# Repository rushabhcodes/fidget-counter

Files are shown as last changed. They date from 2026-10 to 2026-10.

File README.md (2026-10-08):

# MagSafe BLE Fidget Counter — PCB Rev A

> **Current revision 1.0.6: top battery access, a cap with two deliberate release latches, solid bottom cover with 24 magnet pockets, imported CR2032 holder, 0.30 mm via drill / 0.55 mm via land, green mask, double-sided Standard PCBA and ENIG.** TMAG3001A2YBGR is retained. This is a checked prototype ready for supplier quotation/CAM review; the assembly order has not been released.

The default registry entrypoint is `published.circuit.json`, the exact validated routed board and enclosure assembly. `bun run build` renders that saved board; `bun run build:source` rebuilds the editable TSX using the prescribed routing. `bun run check:all` rebuilds and validates the editable TSX, including routing and exported copper. The published circuit is refreshed from that checked build.

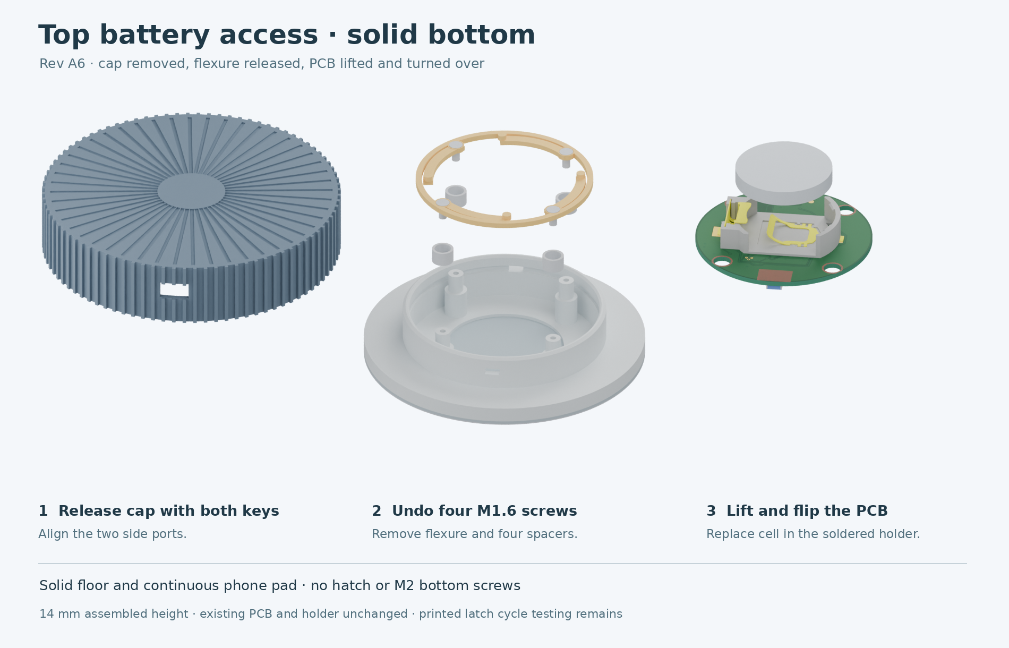
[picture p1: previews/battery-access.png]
Top battery access and revised enclosure


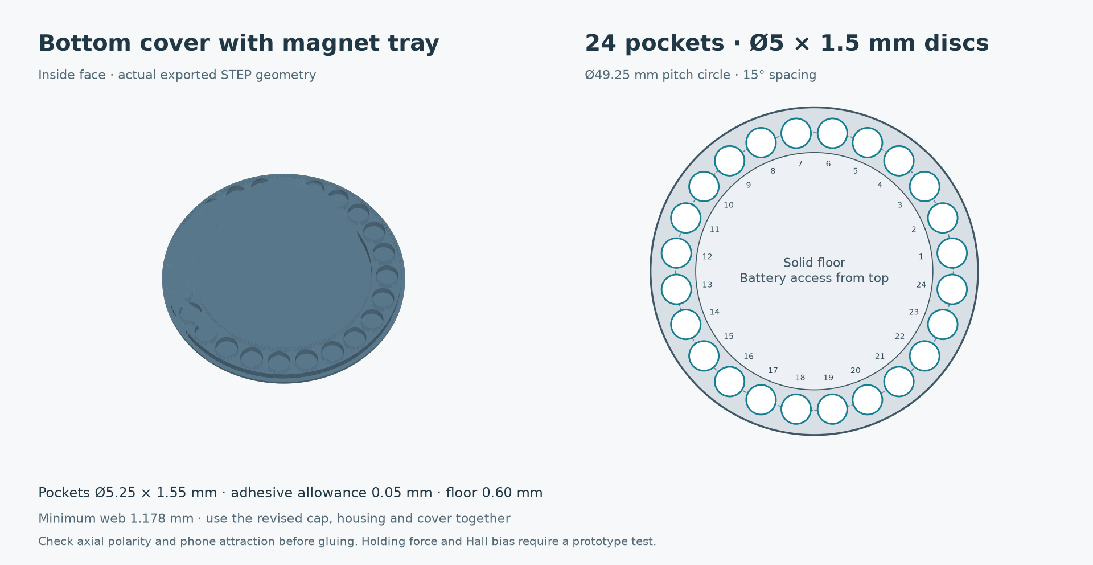
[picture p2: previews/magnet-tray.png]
Bottom cover magnet pockets


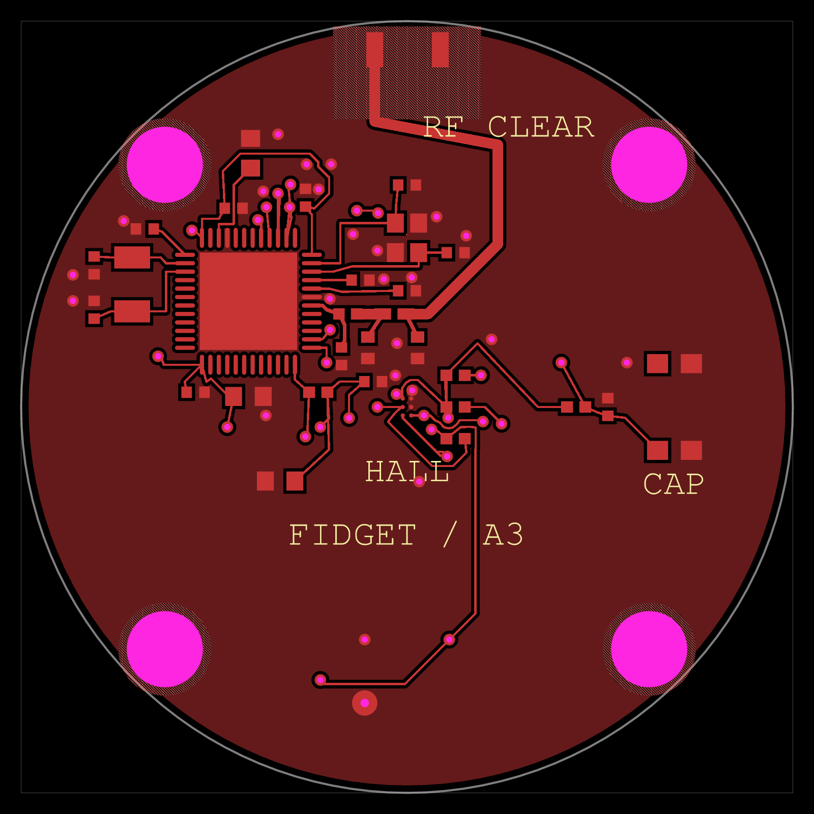
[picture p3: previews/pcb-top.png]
Validated routed PCB


A 36.5 mm circular, two-layer, 1.0 mm PCB for the revised 14.0 mm rotating-cap enclosure. The nRF52810-QFAA reference, its power circuitry, crystals and initial RF matching values come from [seveibar/nrf52810](https://tscircuit.com/seveibar/nrf52810#files), installed as `@tsci/seveibar.nrf52810@0.1.3`. This is a new circular layout; the reference's RF qualification does not carry over.

The central TMAG3001A2 measures the diametric encoder magnet's XY angle. A cap-operated tactile switch supports a two-second count-reset hold in firmware. BT1 is the bottom-mounted MYOUNG BS-08-B2AA020-R holder (JLCPCB C964787), imported with its exact footprint and 3D model. The CR2032 is replaced from above: release the two cap latches, remove the four flexure/PCB screws, then lift and flip the board with its soldered holder. The cell positive face points toward the solid bottom cover. Five underside pogo pads provide SWD access. No LED, charging circuit or tall programming connector is fitted.

## Open and build

```sh
bun install --frozen-lockfile
bun run dev
bun run check:all
```

Use the project's local CLI through `bun run tsci` to keep the tool version consistent with the lockfile. At project initialization, tscircuit 0.0.2748 and CLI 0.1.2253 were verified against the official npm registry. See `bun.lock` for installed dependency versions.

`check:all` runs TypeScript, every TSCI check command, a source build, the full `@tscircuit/checks` validator, and Gerber-derived shorts on both layers. It analyzes trace lengths for every electrical net and requires all eight crystal signal branches to be at most 10 mm with zero vias. Results and source hashes go to `work/`. It fails on design errors, warnings, actionable placement issues or an asynchronous tool exception. Routing difficulty is an advisory congestion estimate; successful routing and DRC determine the final result.

The board uses an explicit parts engine that returns the authored supplier identifiers. Pin roles and manufacturer choices come from the listed datasheets and BOM, so checks do not replace them with remote supplier suggestions. No design-rule check is disabled.

`index.circuit.tsx` defines placement, nets, four schematic sheets and local routing. `routing.ts` uses tscircuit's local custom-router API to load the remaining edited copper branches from `routed-paths.json`. Its terminal signature rejects stale routes after placement/connectivity changes. The supplied routing is prescribed and reproducible; all normal DRC, pour, connection and shorts checks remain enabled. `imports/` contains unmodified TSCI JLCPCB imports with downloaded OBJ/STEP models. `parts.tsx` and `passives.tsx` add electrical pin roles and select those library parts. Imported copper, pad numbers, courtyards and model files are preserved; supplier silkscreen graphics are omitted where the board uses its own legend. Bare diagnostic and programming lands use standard footprint generators. The physical MCU is declared once and split into sheet-local schematic boxes.

## JLCPCB library imports

The parts were located with `tsci search --jlcpcb --json`, matched by exact manufacturer part number, then imported with `tsci import --jlcpcb --download --use-exact-footprint C<number>`. The exact-footprint flag keeps supplier geometry instead of substituting a similar footprint generator. `validation/jlc-imports.json` records the commands, catalog identifiers and SHA-256 hashes of all generated TSX/OBJ/STEP files. Stock returned by search is cached; it is not an assembly reservation.

**SW1 exception:** the existing 2 N KMR223NG ULC LFG / Y78B22324FP has no verified JLCPCB catalog identifier. Its footprint and visual model reuse the imported KMR232NGULCLFS (C221681) geometry: both share the manufacturer's KMR2 package/land drawing. The fitted part remains the original 2 N switch. C221681 is deliberately absent from SW1's supplier identifiers and assembly BOM because it is the 3 N variant. A substitution to that variant awaits the user's preference; exact 2 N procurement or consignment remains open. There are no hand-drawn component copper footprints in the project.

For local 3D output, use `bun run tsci build index.circuit.tsx --glbs --3d-png`. This CLI version's standalone JSON-to-GLB export resolves project-relative model URLs against the registry; its build path resolves downloaded files correctly. Model meshes have been checked in the built GLB. Imported visual models are assembly illustrations, not tolerance-certified mechanical drawings.

## Hardware and firmware handoff

| Signal | nRF52810 GPIO / physical QFAA pin | Peripheral |
|---|---|---|
| SCL | P0.26 / 38 | U2 C2, 10 kΩ pull-up |
| SDA | P0.27 / 39 | U2 C1, 10 kΩ pull-up |
| HALL_INT | P0.28 / 40 | U2 B1, active-low open drain, 10 kΩ pull-up |
| CAP_PRESS | P0.29 / 41 | SW1 closes to GND, 100 kΩ pull-up, 10 nF filter |
| SWDCLK | 25 | TP_SWDCLK |
| SWDIO | 26 | TP_SWDIO |
| nRESET | P0.21 / 24 | TP_RESET, 100 kΩ pull-up |
| LF crystal | P0.00 / 2, P0.01 / 3 | 32.768 kHz |
| HF crystal | XC1 / 34, XC2 / 35 | 32 MHz |

Supply is the CR2032 directly, nominal 3 V. U1 operates from 1.7–3.6 V and U2 from 1.65–3.6 V. Set **DCDCEN = 0**: this retains the reference's LDO-mode circuit, with no DC/DC inductors fitted. DEC pins supply only their associated decoupling capacitors. Configure P0.21 as nRESET if hardware reset is desired; CAP_PRESS clears the count in firmware and is a separate GPIO.

Start I2C at 100 kHz with the fitted 10 kΩ pull-ups. U2 ADDR is grounded: the seven-bit address is **0x34**. Per TI, ADDR is sampled only in standby/continuous mode. Before entering sleep or wake-and-sleep mode, explicitly program the device's I2C address and enable its software address override. Start with the ±240 mT range and XY measurements, check saturation, and calibrate field offsets and gain with the coin cell, phone and attachment magnets installed. Package center is at (0,0); the chip's internal Hall elements have the manufacturer's intrinsic offsets.

At rest, use the sensor's wake-and-sleep mode and a magnetic-change interrupt to wake U1. Clear the interrupt promptly; an asserted open-drain output draws current through R3. Increase the sample rate while moving. Integrate wrapped signed angle differences; count complete 360° increments without incrementing for small reversals across zero. Choose a sampling interval that bounds the maximum expected intersample rotation below 180°, or add velocity-based rejection. Debounce SW1 and clear the stored count after a continuous two-second press. Keep BLE advertising/notification intervals sparse and batch updates. Firmware and a phone app are not included in this PCB project.

## Assembly and tuning

See **MECHANICAL.md** for mounting coordinates, the required cap-pusher change and the imported holder and top battery access. See **BOM.csv** for assembly values and source identifiers. C13/C14 are DNP tuning sites; their initial values describe candidate capacitors, not fitted parts.

The reference's 3.9 nH / 0.8 pF chip matching and 6.8 nH antenna matching are starting values. The new feed and circular ground geometry need RF measurement and tuning in the final enclosure against the intended phone. A 0.5 mm feed width is the retained routing starting value, not a verified 50 Ω transmission line. Confirm the fabricator's actual stackup and recalculate the feed/ground geometry before an RF-qualified production release. Measure crystal startup/frequency and adjust the 12 pF load capacitors if needed.

U2 is a six-ball 0.4 mm-pitch WCSP. The exact JLCPCB/EasyEDA import uses 0.20 mm lands, while TI's recommended land drawing uses 0.23 mm. The imported footprint is retained as requested; the assembler must review this difference and stencil/reflow suitability before an order. The current sensor is cataloged as JLCPCB C31115089; it remains in this design by request. Stock and preorder availability are not guaranteed. The exact SW1 switch has no verified JLCPCB assembly listing; procurement or consignment needs confirmation. The fabrication export adds the core’s missing QFN lead paste apertures at its normal 70% linear size reduction and excludes paste from bare/DNP sites. The generated QFN exposed-pad paste is a single 3.22 × 3.22 mm aperture over the 4.6 × 4.6 mm copper land. Have the assembler review and segment that aperture for its stencil/reflow process before ordering assembly.

The BOM specifies imported Murata RF/passive parts, Yageo resistors and a Samsung 1 µF C10. C10 is CL10B105KA8NNWC (25 V, X7R, ±10%, 0603), replacing the previously unresolved Murata part. All fitted passive footprints and models come from their exact JLCPCB imports. Capacitor DC-bias derating and RF performance still need prototype measurements. `Assembly_Position_Reference.csv` contains authored coordinates and rotations, which the assembler must map to its own component conventions. BT1 is fitted on the underside; the other 29 fitted components are on top. Soldermask covers both ground pours, and vias are tented on both sides.

Both oscillators use native crystal models with electrical length/via constraints. X1 uses the imported manufacturer's pad numbers directly: 1 and 3 are crystal terminals, and 2 and 4 are grounded case pads. Its authored PCB rotation is 90°. X1 is a 32 MHz, 8 pF-load crystal; X2 is 32.768 kHz with a 9 pF load. The four 12 pF external capacitors are initial values that include an allowance for PCB and pin parasitics.

PCB checks verify connectivity and geometry. Physical rotation accuracy, BLE range, current consumption and battery/contact life require a populated prototype. `VALIDATION.md` records the actual final tool results.

## JLCPCB fabrication and assembly settings

Keep U2 TMAG3001A2YBGR. Target **Standard PCBA, both sides**, with **ENIG**, green soldermask, 2 layers, 1 oz copper and 1.0 mm finished thickness. Use regular routed outline tolerance (±0.2 mm), regular minimum via option (0.3 mm drill), and tented vias. The routed design uses **0.30 mm drill / 0.55 mm land**; GPIO escape lands use the same geometry and have no inserted component.

The imported sensor mask bridges are 0.20 mm, so green mask is specified. Printed text is 1.7 mm nominal height with a 0.153 mm stroke; pin-one markers use 0.15 mm strokes. Default passive outlines that overlapped nearby mask openings are omitted. `validation/jlc-geometry-audit.json` records measured copper/drill clearances, and `validation/jlc-gerber-audit.json` checks the exported mask and legend; these independent checks supplement the TSCI checks.

The 36.5 mm circle needs a carrier for Standard PCBA. Ask JLCPCB to panelize the single-board Gerbers into a panel at least 70 × 70 mm, with 5 mm handling rails, tooling holes and fiducials. Use mouse-bite tabs clear of the antenna and mounting holes. Confirm tab locations and finished-circle clearance with CAM; depanelization leaves local tab remnants. The supplied Gerber ZIP is a single-board definition, not a fabricated carrier panel.

The bottom-mounted holder adds a second assembly side; confirm reflow order, retention/fixture needs and any handling charge with JLCPCB. Normal Standard assembly setup, stencil, feeder loading, inspection, ENIG, panelization, component and shipping costs remain. The drill, copper and mask changes aim to avoid unnecessary fabrication options. A supplier quote and CAM review are still required to confirm all charges; no final price or zero-surcharge guarantee has been obtained.

`BOM.csv` distinguishes verified catalog identities, retained reference mappings and unresolved exact-MPN sourcing. `JLCPCB_BOM_Quote_Draft.csv` includes fitted parts only; `JLCPCB_CPL_Quote_Draft.csv` gives single-board positions in millimetres. Both contain 30 designators (29 top and BT1 bottom). Rotations are authored rotations and must be visually matched to JLCPCB's models, particularly U1, U2, X1, X2, ANT1 and SW1. Confirm the QFN exposed-pad stencil apertures with the assembler. ANT1's [catalog listing](https://jlcpcb.com/partdetail/Walsin_TechCorp-RFANT3216120A5T/C127629) carries a fixture notice; confirm whether a fixture is required and its charge. C10, C15 and L2 now have exact imported catalog identifiers. SW1 still requires exact-part sourcing confirmation; U2 and the four crystal load capacitors need stock confirmation for the selected quantity.

The mounting-hole web remains 0.25 mm nominal, inherited from the enclosure. Obtain explicit CAM acceptance, or revise the hole positions and enclosure together. This handoff is ready for supplier review and quotation, with the unresolved items stated; it is not released for an assembly order.

Current primary requirements: [rigid PCB capabilities](https://jlcpcb.com/capabilities/pcb-capabilities), [assembly capabilities](https://jlcpcb.com/capabilities/pcb-assembly-capabilities), [surcharge rules](https://jlcpcb.com/help/article/in-what-cases-will-there-be-charged-extra), [assembly charges](https://jlcpcb.com/help/article/pcb-assembly-price).

## Handoff files

- Root TSX files, package/configuration files and lockfile: editable tscircuit project.
- `verify.mjs`: repeatable full check runner, invoked with `bun run check:all`.
- `published.circuit.json`: exact checked routed circuit used for the registry and supplied exports. The default build writes it to `dist/published/circuit.json`.
- `previews/`: copper layout views, a fitted-part assembly reference and all four schematic sheets in PNG/SVG. `pcb-bottom` shows the actual underside orientation; `pcb-bottom-top-coordinates` retains the source coordinate view. The assembly reference excludes DNP parts, GPIO escape lands and bare test/contact interfaces; crystal manufacturer pin numbering is documented above. Library model downloads are included under `imports/`, with the full device GLB and PNG at `previews/3d.*` and the unchanged bare PCB view at `previews/pcb-3d.*`.
- `fabrication/`: prototype Gerber/drill ZIP and assembly position reference CSV.
- `BOM.csv` and `netlist.txt`: assembly intent and electrical connectivity.
- `mechanical/`: all four compatible printed enclosure parts in STL/STEP, editable CadQuery source/parameters and geometry validation.
- `validation/`: final check logs, warning inventory and source/circuit hashes.

Treat the Gerbers as a prototype review handoff. Resolve the thin mounting-hole web with the fabricator and the stencil/land-pattern details with the assembler before placing an order. RF tuning and magnetic calibration remain prototype measurements.

The fabrication ZIP contains Gerber and drill files only. Use the separate authored BOM and assembly position reference; automatically generated supplier BOM/rotation files have been omitted.

Run `bun run export:gerbers` after `bun run check:all` to produce the fabrication ZIP; this preserves supplier copper geometry and fills the missing QFN lead paste records. To repeat the independent JLC geometry/export audits, install `validation/requirements.txt` into a local Python virtual environment, then run `validation/check-jlc.py published.circuit.json` and `validation/check-jlc-gerbers.py fabrication/Fidget_Counter_RevA_Prototype_Gerbers.zip published.circuit.json` from the project root. These produce reports in `work/` and fail on the measured rule violations.

## Enclosure in the circuit's 3D view

`index.circuit.tsx` wraps the board in `<assembly.device>` and adds `EnclosureAssembly` from `enclosure.tsx`. Its 12 named `<assembly.cadassembly>` elements load the existing enclosure geometry alongside the actual populated PCB. There are no duplicate electronics or holder dummies. The three outer shells are translucent to expose the interior; STL/STEP solids retain their original geometry.

The models use millimetres and Z-up assembly coordinates. Their offset is Z = −7.6 mm because tscircuit places the PCB midplane at Z = 0. This preserves the released cap, holder and cell stack. The central encoder uses the user-specified diametrically magnetized neodymium Ø5 × 1.5 mm disc, a Ø5.2 mm pocket and a 0.2 mm roof shim. Its nominal released/pressed sensor gaps remain 1.8/1.3 mm; magnet grade and field calibration are unverified. `mechanical/Circuit_Models/manifest.json` records model bounds and hashes. The bottom cover now locates 24 separate Ø5 × 1.5 mm discs on a Ø49.25 mm pitch circle. Its inside-face pockets are Ø5.25 × 1.55 mm, including 0.05 mm adhesive allowance. The housing accepts the thicker cover tray and a Ø44.05 / Ø54.45 × 0.7 mm steel backing ring; overall enclosure height remains 14 mm. Use this revision's cap, housing and solid bottom cover together. The two release keys and PCB lift pick are included as printable tools. See `MECHANICAL.md` for loading order and polarity checks; holding force, ordered magnetization and phone compatibility are unverified.

The CadQuery builder also writes `Circuit_Models/` into its output directory. After revising the CAD, copy those generated assets into `mechanical/Circuit_Models/`, rebuild the source, then run `bun run check:enclosure` to verify model alignment and unchanged electrical geometry. The downloadable GLB is compacted for the registry upload limit. It preserves every position, triangle index, node transform, electronic model and board texture byte-for-byte; viewers derive flat normals for the untextured enclosure models. Repeat this export step after a source build:

```sh
python3 validation/compact-glb.py dist/index/3d.glb previews/3d.glb --report validation/compact-glb-audit.json
```

The assembly API follows the [TSCI cadassembly documentation](https://docs.tscircuit.com/elements/assembly-cadassembly).

## Primary design sources

- Reference board: https://tscircuit.com/seveibar/nrf52810#files
- Nordic reference circuitry: https://docs.nordicsemi.com/r/bundle/ps_nrf52810/page/ref_circuitry.html
- TI TMAG3001 datasheet, SLYS053C: https://www.ti.com/lit/ds/symlink/tmag3001.pdf
- MYOUNG holder drawing (BS-08-B2AA020 family, maximum height 5.8 mm): https://xonstorage.z8.web.core.windows.net/pdf/myoung_bs08b2aa020_apr22_xonlink.pdf
- C&K KMR2 datasheet: https://www.ckswitches.com/media/1479/kmr2.pdf
- TSCI JLCPCB import workflow: https://docs.tscircuit.com/command-line/tsci-import

## Published project

- GitHub: https://github.com/rushabhcodes/fidget-counter
- Tscircuit registry: https://tscircuit.com/rushabhcodes/fidget-counter

`validation/` retains the complete source-build and JLC review results for this 0.30 mm revision. `validation/history/` preserves previous publication reports. Current reports and imported-file provenance are in `validation/`. The saved circuit is byte-identical to the validated source-build output.

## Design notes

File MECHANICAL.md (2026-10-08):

# PCB / enclosure interface — top-access revision 1.0.6

Coordinates are millimetres in a top view, relative to the rotation axis. The board is Ø36.5 × 1.0 mm, with four Ø3.6 mm nonplated mounting holes at (±11.45513, ±11.45513). Their thin 0.25 mm nominal edge web still requires fabricator acceptance. Printed shoulders and bushings support the board.

The revised enclosure is **14.0 mm high**. PCB bottom/top planes are Z=7.1/8.1. U2 is centered at (0,0); U1 is the 6 × 6 mm QFN at (-7.5,5); SW1 is centered at (12.65,0). The encoder magnet's lower face is Z=10.4, leaving nominal sensor package clearance of 1.8 mm released and 1.3 mm pressed. The cap pocket is Ø5.2 mm with a 0.2 mm roof shim; the magnet lower face stays at Z=10.4 mm. Use a diametrically magnetized neodymium Ø5 × 1.5 mm magnet and calibrate with the final phone and cell installed.

The Ø61.6 mm cap retains its full circumference grip, extending down to Z=1.0. Its pressed lower edge remains 0.5 mm above the phone plane. The annular switch pusher uses `pcb_top + 2.15`: nominal 0.25 mm free clearance above the 1.9 mm actuator, followed by nominal 0.25 mm switch displacement during the cap's 0.5 mm travel. Fit-test the switch and printed stack; the tactile switch must not act as the structural stop.

## Commercial CR2032 holder

BT1 is **MYOUNG BS-08-B2AA020-R, JLCPCB C964787**, mounted on the PCB underside. The exact footprint, pad numbers and OBJ/STEP model come from `tsci import --jlcpcb --download --use-exact-footprint C964787`; the imported files are unchanged. The manufacturer drawing specifies 24.1 × 15.7 mm body dimensions and **5.8 mm maximum height**. Clearance uses that maximum rather than the library model's 5.3 mm height. The holder's maximum envelope leaves 0.5 mm above the solid floor.

The footprint origin is (-1.2,0), which centers the manufacturer drawing's cell axis at (0,0) after the bottom-side mirror. Pin 1 is positive at (-12.999913,0), with a 3.5 × 3.8 mm SMT land; pin 2 is negative at (9.499915,0), with a 5.7 × 2.8 mm SMT land. These coordinates are top-view coordinates. Two regular tented routing vias at (2,-11) and (-2,-11) preserve the original power distribution; they are not battery contacts or wire attachment points.

Insert the CR2032 **positive face toward the solid bottom cover**, negative face toward the PCB. Insert the battery after PCB reflow. The commercial holder supplies retention and contacts. The bottom cover is permanently closed.

## Top battery access and cap release

The cap now has **two 0.6 mm PETG latch tongues** instead of six broad retention segments. Two 6 × 3.5 mm windows in the grip line up with two 3 × 1.4 mm radial ports in the housing, at 90° and 270°. The retention roof above the ports remains continuous, so aligning the ports alone does not unlock the cap. The 0.25 mm nominal lip engagement and 0.5 mm button travel are retained. Use PETG for the cap and flexure; repeated release of the thin latches has not been physically tested.

1. Remove the device from the phone. Rotate the cap until both grip windows align with the housing ports.
2. Insert the two printed `Cap_Release_Key_Print_2` keys through the windows and ports. Press both keys inward until their shoulders meet the housing, then gently lift the cap about 0.5 mm. Withdraw the keys and lift the cap clear. Do not force a latch that does not release; fit-test the port/key pair first.
3. Undo the **four M1.6 screws** securing the flexure and PCB spacers. Lift away the flexure and four bushings. Keep the loose bushings together.
4. Use the nonconductive `PCB_Lift_Pick` at the PCB edges near 0° and 180°, away from the parts. Raise both edges gradually, then lift the PCB, soldered holder and cell together straight upward along the four columns. Grip the PCB edge; do not pull on components or solder tails.
5. Turn the lifted PCB over, release the cell from the holder's open sides and fit a fresh CR2032. Positive face points away from the PCB.
6. Lower the board onto its shoulders and columns, refit the four bushings, flexure and screws, then snap the cap back on. Confirm free rotation, return travel and cap retention before use.

The keys have 1.0 × 2.4 mm blades and shoulders that limit nominal latch deflection to 0.35 mm. At that deflection the lip clears the bore by 0.10 mm and the latch inner face clears the PCB by 0.20 mm. The approximate release strain is 1.87%; this is not FEA or a measured fatigue limit. CAD checks both key paths, the intact retention roof and nine upward board/holder/cell positions from 0 to 24 mm. The initial edge-pick corridors clear rigid solids; actual pick leverage and component clearances require a printed/populated prototype.

There is **no bottom hatch, hatch seam, hatch post or M2 hatch screw**. The bottom cover and protective pad are continuous. The four existing top fasteners remain the reusable PCB mount.

The exported holder STEP contains its unloaded negative spring contact. Its 2.62 mm³ intersection with the nominal cell is reported separately as spring preload geometry; the cell has zero intersection with the rigid holder body. Contact deflection, insertion/removal motion, retention force and printed tolerances require a physical fit test. The top-service STEP illustrates the lifted and flipped board; cell insertion/removal from the spring holder is not a simulated trajectory.

## Programming and clearance

SWD pads are at Y=-14 and X=-4,-2,0,2,4, ordered VDD, GND, SWDIO, SWDCLK, nRESET in a top view. Viewed directly underneath, their order is **R, C, D, G, V**, matching the legend. Lift the PCB through the top and turn it over for programming. Use a fixture with narrow probes. VDD is a target-voltage reference; remove the primary cell before deliberately powering the board from the programmer.

TP_GND has a 0.4 mm plated drill; the remaining four 1.2 mm pogo pads are undrilled. GPIO diagnostic lands use 0.30 mm drills and 0.55 mm lands, with no fitted parts. All routing vias are tented on both sides. The holder's insulating housing separates the cell from PCB copper.

The antenna keepout is X=-3.5…3.5, Y=13.6…18.0 on both layers. Keep metal and attachment parts away from this volume where practical. The phone, cell and attachment magnets still affect RF and Hall readings.

## Bottom disc magnet tray

The ordered Ø5 × 1.5 mm discs replace the reserved segmented-ring magnet envelope. **24 inside-face pockets** in `Bottom_Cover` sit on a Ø49.25 mm pitch circle, spaced 15° apart with the first center at 7.5°. Each pocket is **Ø5.25 mm, 1.55 mm deep**: 1.5 mm magnet plus 0.05 mm nominal adhesive thickness. Diametral clearance is 0.25 mm. Adjacent pockets have 1.178 mm nominal plastic web, with 1.000 mm inner and 0.800 mm outer tray walls; a 0.800 mm continuous housing rim supports the flange above. The phone-facing skin remains 0.6 mm, plus the separate 0.2 mm protective pad. Print a fit coupon or test one pocket before committing the magnets; printer and magnet tolerances may need adjustment.

The pocket walls are a raised tray integral with the bottom cover. The stationary housing has clearance for that tray and an upper recess for a continuous **steel backing ring, ID44.05 × OD54.45 × 0.7 mm**. This is a separate metal reference part, not a printed magnet or a verified magnetic shield. Both it and the discs load from below while the cover is off. A backing ring cannot pass through individual Ø5.25 mm holes, which is why the locating pockets are in the separate cover rather than trapped under a housing roof.

Insert the backing ring into the housing recess first. Check the ordered magnets' axial polarity and attraction against the intended phone or case before gluing. Fit 24 discs into the cover pockets with a thin adhesive layer beneath each disc. Their upper faces sit flush with the tray at Z=2.35 mm, and the backing ring starts at Z=2.40 mm. Dry-fit the loaded cover, then bond it to the housing's mating faces. Subsequent battery service uses the top opening. Use the **new cap, housing and solid bottom cover together**. The PCB, soldered holder and flexure retain their geometry and assembled height.

The custom disc layout is a mechanical prototype, not a MagSafe-qualified array. The purchased part's magnetization direction has not been confirmed. Polarity distribution, holding/sliding/rotation force, sensor offset/saturation and BLE performance require tests with the actual assembled phone. Do not assume that a uniform axial-disc circle reproduces Apple's prescribed ring polarity. The central encoder magnet remains diametrically magnetized and separate from these attachment magnets.

## Editable enclosure and supplied parts

`build_enclosure.py` and `enclosure-parameters.json` regenerate the assembly with CadQuery ≥2.6. Run from the project root:

```sh
python mechanical/build_enclosure.py --out work/enclosure
```

`Print_STL/` contains four main enclosure parts: Rotating_Cap, Stationary_Housing, Flexure_Retention_System and Bottom_Cover. Also print four PCB spacers, two cap release keys and one PCB lift pick from their named STL files. Corresponding editable solids are in `STEP_Parts/`. Use the complete revised cap/housing/cover set; older caps and housing ports do not form the new release mechanism.

Released, pressed, exploded and top-service assemblies are included in the downloadable mechanical handoff. Electronics other than the holder are board/key-package bounding references; the circuit now combines the actual populated PCB with the released enclosure in `previews/3d.glb`. Its 12 assembly models exclude these electronic bounding dummies and the duplicate holder. `previews/pcb-3d.glb` retains the bare board view. The three outer shells are translucent in the circuit viewer. The builder also exports aligned OBJ/MTL files in `Circuit_Models/`; copy these into `mechanical/Circuit_Models/` after a CAD revision. Attachment discs now match the ordered dimensions; magnetic performance is untested. The flexure calculation is an approximate cantilever estimate rather than FEA or a measured return force.

Sources: [MYOUNG holder drawing](https://xonstorage.z8.web.core.windows.net/pdf/myoung_bs08b2aa020_apr22_xonlink.pdf), [JLCPCB holder listing](https://jlcpcb.com/partdetail/MYOUNG-BS_08_B2AA020R/C964787), [C&K KMR2 drawing](https://www.ckswitches.com/media/1479/kmr2.pdf).

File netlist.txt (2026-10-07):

COMPONENTS:
 - GPIO_SCL: 
 - GPIO_SDA: 
 - GPIO_HALL_INT: 
 - U1: NRF52810-QFAA-R
 - BT1: BT1, source_component
 - C4: 100nF capacitor
 - C9: 4.7uF capacitor
 - C15: 22uF capacitor
 - C5: 100nF capacitor
 - C7: 100pF capacitor
 - C8: 100nF capacitor
 - C10: 1uF capacitor
 - C16: 100nF capacitor
 - C18: 100nF capacitor
 - TP_VDD: TP_VDD, source_component
 - TP_GND: TP_GND, source_component
 - TP_SWDIO: TP_SWDIO, source_component
 - TP_SWDCLK: TP_SWDCLK, source_component
 - TP_RESET: TP_RESET, source_component
 - R4: 100kΩ resistor
 - U2: TMAG3001A2YBGR
 - C6: 100nF capacitor
 - R1: 10kΩ resistor
 - R2: 10kΩ resistor
 - R3: 10kΩ resistor
 - SW1: SW1, source_component
 - R5: 100kΩ resistor
 - C17: 10nF capacitor
 - X1: X1, source_component
 - C1: 12pF capacitor
 - C2: 12pF capacitor
 - X2: X2, source_component
 - C11: 12pF capacitor
 - C12: 12pF capacitor
 - L1: L1, source_component
 - L2: L2, source_component
 - C3: 0.8pF capacitor
 - C13: 0.5pF capacitor
 - C14: 0.5pF capacitor
 - ANT1: RFANT3216120A5T

NET: U1_DEC1
  - U1 DEC1
  - C5 pin1

NET: U1_DEC2
  - U1 DEC2
  - C7 pin1

NET: U1_DEC3
  - U1 DEC3
  - C8 pin1

NET: U1_DEC4
  - U1 DEC4
  - C10 pin1

NET: SWDIO
  - U1 SWDIO
  - TP_SWDIO pin1

NET: SWDCLK
  - U1 SWDCLK
  - TP_SWDCLK pin1

NET: NRESET
  - U1 P0_21
  - R4 pin2
  - TP_RESET pin1

NET: SCL
  - U2 SCL
  - R1 pin2
  - U1 P0_26
  - GPIO_SCL SIGNAL

NET: SDA
  - U2 SDA
  - R2 pin2
  - U1 P0_27
  - GPIO_SDA SIGNAL

NET: HALL_INT
  - U2 INT
  - R3 pin2
  - U1 P0_28
  - GPIO_HALL_INT SIGNAL

NET: VBAT
  - R5 pin1
  - C6 pin1
  - U2 VCC
  - R3 pin1
  - R2 pin1
  - R1 pin1
  - U1 VDD2
  - C18 pin1
  - C16 pin1
  - C15 pin1
  - C4 pin1
  - BT1 pin1 (+)
  - U1 VDD3
  - U1 VDD1
  - C9 pin1
  - R4 pin1
  - TP_VDD pin1

NET: CAP_PRESS
  - SW1 A1
  - SW1 A
  - U1 P0_29
  - R5 pin2
  - C17 pin1

NET: U1_XC1
  - C1 pin1
  - U1 XC1
  - X1 pin1

NET: U1_XC2
  - C2 pin1
  - U1 XC2
  - X1 pin3

NET: X2_pos
  - C11 pin1
  - U1 P0_00
  - X2 pin1 (+)

NET: X2_neg
  - C12 pin1
  - U1 P0_01
  - X2 pin2 (-)

NET: U1_ANT
  - C3 pin1
  - U1 ANT
  - L1 pin1

NET: C13_pos
  - C13 pin1 (+)
  - L1 pin2
  - L2 pin1

NET: ANT1_feed
  - C14 pin1 (+)
  - L2 pin2
  - ANT1 feed

NET: GND
  - C14 pin2 (-)
  - C13 pin2 (-)
  - C3 pin2
  - C12 pin2
  - C11 pin2
  - C2 pin2
  - SW1 B2
  - SW1 B
  - C6 pin2
  - U2 ADDR
  - U2 GND
  - C7 pin2
  - C16 pin2
  - C15 pin2
  - C4 pin2
  - BT1 pin2 (-)
  - TP_GND pin1
  - C1 pin2
  - X1 pin4
  - X1 pin2
  - C10 pin2
  - C8 pin2
  - C5 pin2
  - C17 pin2
  - C18 pin2
  - C9 pin2
  - U1 VSS1
  - U1 VSS2
  - U1 EP

COMPONENT_PINS:
GPIO_SCL
- pin1(SIGNAL): NETS(SCL)

GPIO_SDA
- pin1(SIGNAL): NETS(SDA)

GPIO_HALL_INT
- pin1(SIGNAL): NETS(HALL_INT)

U1 (NRF52810-QFAA-R)
- pin1(DEC1): NETS(U1_DEC1)
- pin2(P0_00, XL1): NETS(X2_pos)
- pin3(P0_01, XL2): NETS(X2_neg)
- pin4(P0_02, AIN0): NOT_CONNECTED
- pin5(P0_03, AIN1): NOT_CONNECTED
- pin6(P0_04, AIN2): NOT_CONNECTED
- pin7(P0_05, AIN3): NOT_CONNECTED
- pin8(P0_06): NOT_CONNECTED
- pin9(P0_07): NOT_CONNECTED
- pin10(P0_08): NOT_CONNECTED
- pin11(P0_09): NOT_CONNECTED
- pin12(P0_10): NOT_CONNECTED
- pin13(VDD1): NETS(VBAT)
- pin14(P0_11): NOT_CONNECTED
- pin15(P0_12): NOT_CONNECTED
- pin16(P0_13): NOT_CONNECTED
- pin17(P0_14): NOT_CONNECTED
- pin18(P0_15): NOT_CONNECTED
- pin19(P0_16): NOT_CONNECTED
- pin20(P0_17): NOT_CONNECTED
- pin21(P0_18): NOT_CONNECTED
- pin22(P0_19): NOT_CONNECTED
- pin23(P0_20): NOT_CONNECTED
- pin24(P0_21, nRESET): NETS(NRESET)
- pin25(SWDCLK): NETS(SWDCLK)
- pin26(SWDIO): NETS(SWDIO)
- pin27(P0_22): NOT_CONNECTED
- pin28(P0_23): NOT_CONNECTED
- pin29(P0_24): NOT_CONNECTED
- pin30(ANT): NETS(U1_ANT)
- pin31(VSS2): NETS(GND)
- pin32(DEC2): NETS(U1_DEC2)
- pin33(DEC3): NETS(U1_DEC3)
- pin34(XC1): NETS(U1_XC1)
- pin35(XC2): NETS(U1_XC2)
- pin36(VDD3): NETS(VBAT)
- pin37(P0_25): NOT_CONNECTED
- pin38(P0_26): NETS(SCL)
- pin39(P0_27): NETS(SDA)
- pin40(P0_28, AIN4): NETS(HALL_INT)
- pin41(P0_29, AIN5): NETS(CAP_PRESS)
- pin42(P0_30, AIN6): NOT_CONNECTED
- pin43(P0_31, AIN7): NOT_CONNECTED
- pin44(NC): NOT_CONNECTED
- pin45(VSS1): NETS(GND)
- pin46(DEC4): NETS(U1_DEC4)
- pin47(DCC): NOT_CONNECTED
- pin48(VDD2): NETS(VBAT)
- pin49(EP): NETS(GND)

BT1 (BS-08-B2AA020-R)
- pin1(anode, pos, left): NETS(VBAT)
- pin2(cathode, neg, right): NETS(GND)

C4 (100nF undefined)
- pin1: NETS(VBAT)
- pin2: NETS(GND)

C9 (4.7uF undefined)
- pin1: NETS(VBAT)
- pin2: NETS(GND)

C15 (22uF undefined)
- pin1: NETS(VBAT)
- pin2: NETS(GND)

C5 (100nF undefined)
- pin1: NETS(U1_DEC1)
- pin2: NETS(GND)

C7 (100pF undefined)
- pin1: NETS(U1_DEC2)
- pin2: NETS(GND)

C8 (100nF undefined)
- pin1: NETS(U1_DEC3)
- pin2: NETS(GND)

C10 (1uF undefined)
- pin1: NETS(U1_DEC4)
- pin2: NETS(GND)

C16 (100nF undefined)
- pin1: NETS(VBAT)
- pin2: NETS(GND)

C18 (100nF undefined)
- pin1: NETS(VBAT)
- pin2: NETS(GND)

TP_VDD
- pin1: NETS(VBAT)

TP_GND
- pin1: NETS(GND)

TP_SWDIO
- pin1: NETS(SWDIO)

TP_SWDCLK
- pin1: NETS(SWDCLK)

TP_RESET
- pin1: NETS(NRESET)

R4 (100kΩ undefined)
- pin1(anode, pos, left): NETS(VBAT)
- pin2(cathode, neg, right): NETS(NRESET)

U2 (TMAG3001A2YBGR)
- pin1(VCC, A1): NETS(VBAT)
- pin2(INT, N_INT, B1): NETS(HALL_INT)
- pin3(SDA, C1): NETS(SDA)
- pin4(ADDR, A2): NETS(GND)
- pin5(GND, B2): NETS(GND)
- pin6(SCL, C2): NETS(SCL)

C6 (100nF undefined)
- pin1: NETS(VBAT)
- pin2: NETS(GND)

R1 (10kΩ undefined)
- pin1(anode, pos, left): NETS(VBAT)
- pin2(cathode, neg, right): NETS(SCL)

R2 (10kΩ undefined)
- pin1(anode, pos, left): NETS(VBAT)
- pin2(cathode, neg, right): NETS(SDA)

R3 (10kΩ undefined)
- pin1(anode, pos, left): NETS(VBAT)
- pin2(cathode, neg, right): NETS(HALL_INT)

SW1 (KMR223NG ULC LFG / Y78B22324FP)
- pin1(A1): NETS(CAP_PRESS)
- pin2(B2): NETS(GND)
- pin3(B): NETS(GND)
- pin4(A): NETS(CAP_PRESS)

R5 (100kΩ undefined)
- pin1(anode, pos, left): NETS(VBAT)
- pin2(cathode, neg, right): NETS(CAP_PRESS)

C17 (10nF undefined)
- pin1: NETS(CAP_PRESS)
- pin2: NETS(GND)

X1 (X201632MKB4SI)
- pin1(left1, X1): NETS(U1_XC1)
- pin2(gnd2, top1, gnd1): NETS(GND)
- pin3(right1, X2): NETS(U1_XC2)
- pin4(gnd1, bottom1, gnd2): NETS(GND)

C1 (12pF undefined)
- pin1: NETS(U1_XC1)
- pin2: NETS(GND)

C2 (12pF undefined)
- pin1: NETS(U1_XC2)
- pin2: NETS(GND)

X2 (ABS07-32.768KHZ-9-T)
- pin1(pos, left, X1): NETS(X2_pos)
- pin2(neg, right, X2): NETS(X2_neg)

C11 (12pF undefined)
- pin1: NETS(X2_pos)
- pin2: NETS(GND)

C12 (12pF undefined)
- pin1: NETS(X2_neg)
- pin2: NETS(GND)

L1 (LQG15HS3N9B02D)
- pin1: NETS(U1_ANT)
- pin2: NETS(C13_pos)

L2 (LQG15HS6N8G02D)
- pin1: NETS(C13_pos)
- pin2: NETS(ANT1_feed)

C3 (0.8pF undefined)
- pin1: NETS(U1_ANT)
- pin2: NETS(GND)

C13 (0.5pF undefined)
- pin1(anode, pos, left): NETS(C13_pos)
- pin2(cathode, neg, right): NETS(GND)

C14 (0.5pF undefined)
- pin1(anode, pos, left): NETS(ANT1_feed)
- pin2(cathode, neg, right): NETS(GND)

ANT1 (RFANT3216120A5T)
- pin1(feed): NETS(ANT1_feed)
- pin2(NC): NOT_CONNECTED

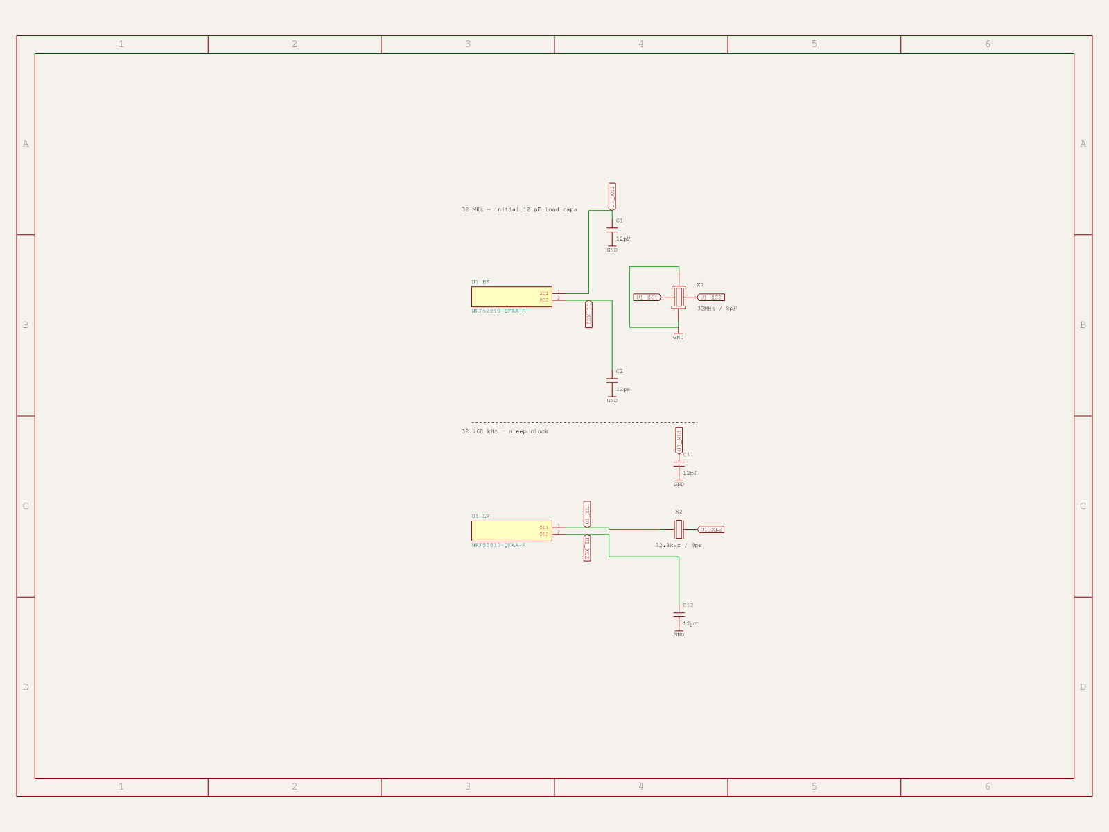
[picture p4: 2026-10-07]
previews/schematic-3-clocks.png

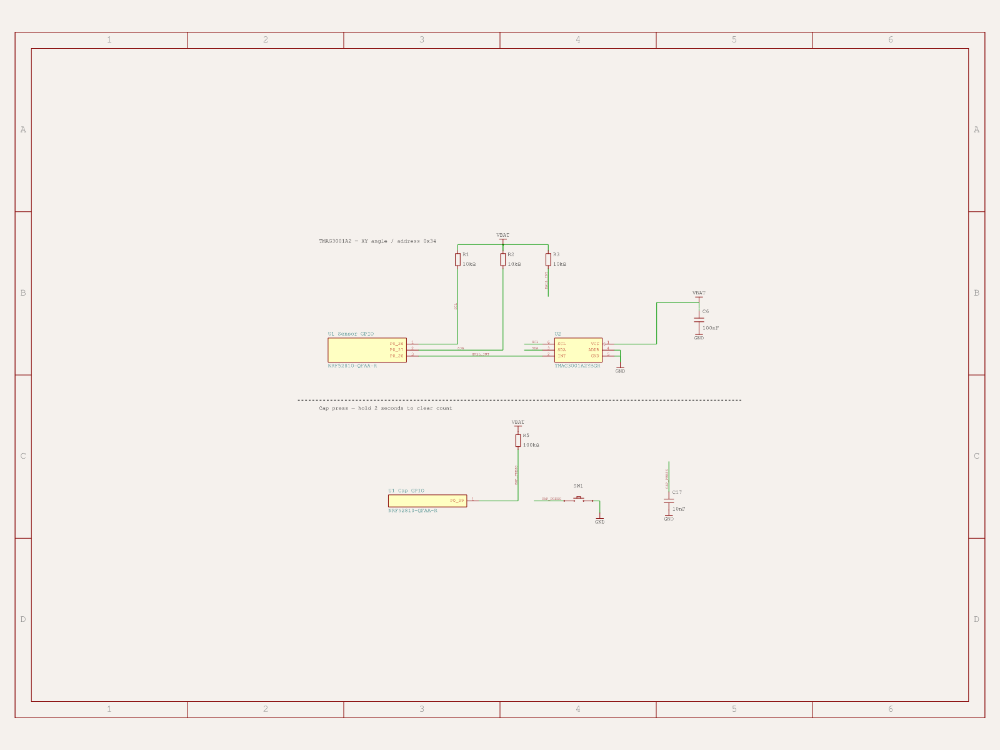
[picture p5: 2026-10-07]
previews/schematic-2-sensor-button.png

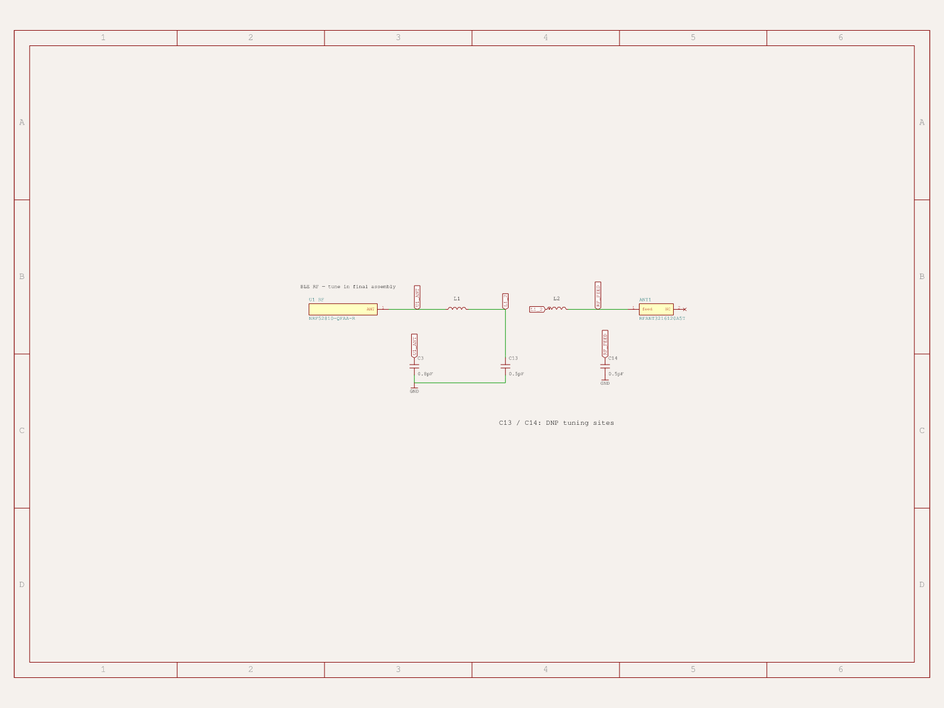
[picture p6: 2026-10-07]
previews/schematic-4-rf.png

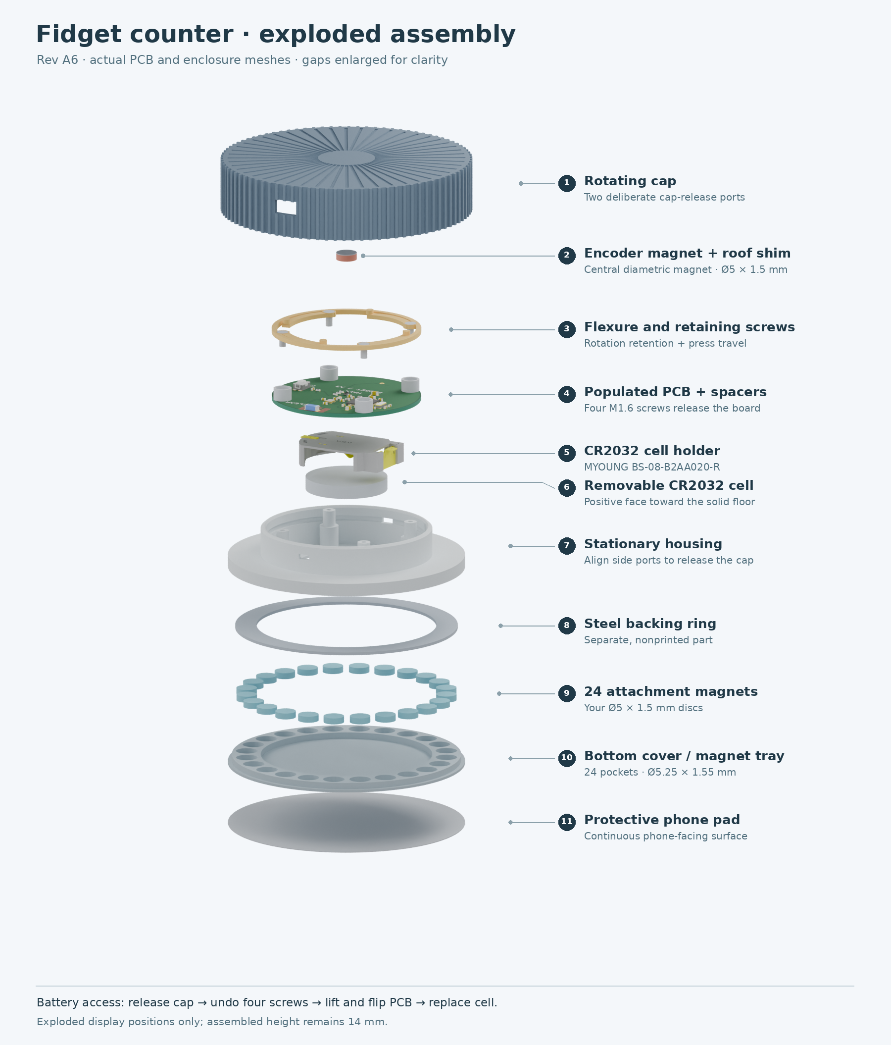
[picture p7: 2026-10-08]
previews/exploded.png

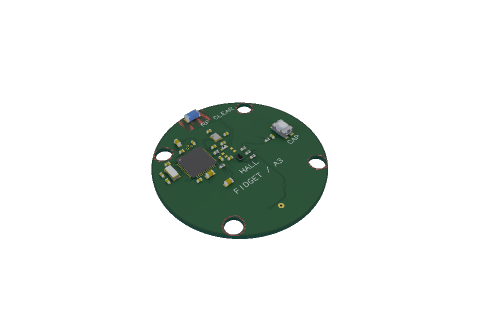
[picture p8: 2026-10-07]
previews/pcb-3d.png

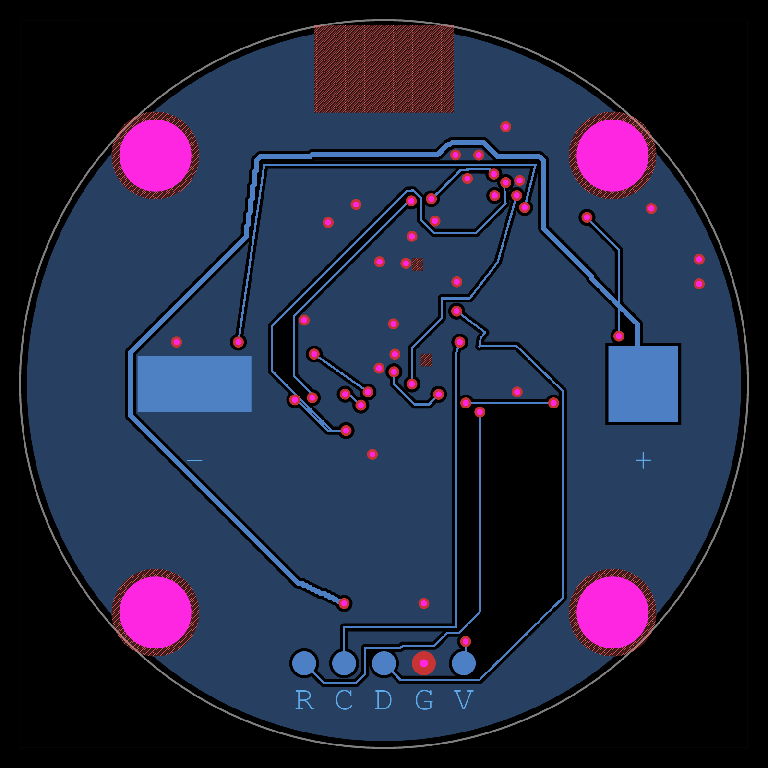
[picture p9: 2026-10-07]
previews/pcb-bottom.png

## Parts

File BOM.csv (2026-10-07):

References | Quantity | Value_or_part | Package | Manufacturer_or_source | Assembly | Notes | Manufacturer_part_number | Source_url | JLCPCB_part_number | Sourcing_status
U1 | 1 | nRF52810-QFAA-R | QFN48 6x6mm 0.4mm pitch | Nordic / JLCPCB C141828 | FIT | Reference QFAA pin map; LDO mode only | nRF52810-QFAA-R |  | C141828 | Exact JLCPCB library import verified; current assembly stock/preorder must be confirmed in quote
U2 | 1 | TMAG3001A2YBGR | WCSP6 YBG 0.4mm pitch | Texas Instruments / JLCPCB C31115089 | FIT | Retain current sensor; Standard PCBA and ENIG; confirm availability/preorder; max package height 0.5mm | TMAG3001A2YBGR |  | C31115089 | Exact JLCPCB library import verified; current assembly stock/preorder must be confirmed in quote
X1 | 1 | X201632MKB4SI | 2016 4-pad crystal | JLCPCB C718072 | FIT | 32MHz; 8pF load; ±10ppm; same manufacturer pad geometry as reference | X201632MKB4SI | https://jlcpcb.com/partdetail/X201632MKB4SI/C718072 | C718072 | Exact JLCPCB library import verified; current assembly stock/preorder must be confirmed in quote
X2 | 1 | ABS07-32.768KHZ-9-T | ABS07 2-pad crystal | Abracon / JLCPCB C179635 | FIT | 32.768kHz 9pF nominal load | ABS07-32.768KHZ-9-T |  | C179635 | Exact JLCPCB library import verified; current assembly stock/preorder must be confirmed in quote
ANT1 | 1 | RFANT3216120A5T | 3216 ceramic antenna | Walsin / JLCPCB C127629 | FIT | Tune matching in final assembly; catalog fixture notice: confirm fixture necessity/charge in quote | RFANT3216120A5T |  | C127629 | Exact JLCPCB library import verified; current assembly stock/preorder must be confirmed in quote
SW1 | 1 | KMR223NG ULC LFG / Y78B22324FP | KMR2 4.6x2.8mm package, 1.9mm actuator height | C&K / Littelfuse | FIT | 1.9mm nominal height; 2N actuation; gold low-current contacts; shared imported KMR2 geometry from C221681; C221681 is 3N and is not this fitted part | KMR223NG ULC LFG / Y78B22324FP |  |  | Exact MPN assembly sourcing not verified; procurement or consignment required
L1 | 1 | 3.9nH | 0402 | Murata | FIT | 3.9nH ±0.1nH; RF matching starting value | LQG15HS3N9B02D | https://www.mouser.com/datasheet/3/76/1/JELF243B-0010.pdf | C5452416 | Exact JLCPCB library import verified; current assembly stock/preorder must be confirmed in quote
L2 | 1 | 6.8nH | 0402 | Murata | FIT | 6.8nH ±2%; tune with antenna | LQG15HS6N8G02D | https://www.mouser.com/datasheet/3/76/1/JELF243B-0010.pdf | C521064 | Exact JLCPCB library import verified; current assembly stock/preorder must be confirmed in quote
C3 | 1 | 0.8pF | 0402 | Murata | FIT | 0.8pF ±0.05pF; 50V C0G high-Q RF shunt | GJM1555C1HR80WB01D | https://www.murata.com/en-us/products/productdetail?partno=GJM1555C1HR80WB01%23 | C88902 | Exact JLCPCB library import verified; current assembly stock/preorder must be confirmed in quote
C13 C14 | 2 | 0.5pF candidate | 0402 | C0G NP0 capacitor supplier | DNP | Optional RF shunts; pads remain on PCB |  |  |  | Excluded from SMT assembly
C1 C2 C11 C12 | 4 | 12pF | 0402 | Murata | FIT | 12pF ±5%; 50V C0G; initial load caps; verify oscillator frequency | GRM1555C1H120JA01D | https://www.murata.com/en-us/products/productdetail?partno=GRM1555C1H120JA01%23 | C76948 | Exact JLCPCB library import verified; current assembly stock/preorder must be confirmed in quote
C7 | 1 | 100pF | 0402 | Murata | FIT | 100pF ±5%; 50V C0G; DEC2 decoupling | GRM1555C1H101JA01D | https://www.murata.com/en-us/products/productdetail?partno=GRM1555C1H101JA01%23 | C77177 | Exact JLCPCB library import verified; current assembly stock/preorder must be confirmed in quote
C4 C5 C6 C8 C16 C18 | 6 | 100nF | 0402 | Murata | FIT | 100nF ±10%; 16V X7R; 0.55mm max height | GRM155R71C104KA88D | https://www.murata.com/en-us/products/productdetail?partno=GRM155R71C104KA88%23 | C71629 | Exact JLCPCB library import verified; current assembly stock/preorder must be confirmed in quote
C10 | 1 | 1uF | 0603 | Samsung / JLCPCB C730442 | FIT | 1uF ±10%; 25V X7R; DEC4 decoupling; replaces unresolved Murata part | CL10B105KA8NNWC | https://jlcpcb.com/partdetail/778841-CL10B105KA8NNWC/C730442 | C730442 | Exact JLCPCB library import verified; current assembly stock/preorder must be confirmed in quote
C9 | 1 | 4.7uF | 0603 | Murata | FIT | 4.7uF ±10%; 6.3V X5R; effective capacitance derates with DC bias | GRM188R60J475KE19D | https://www.murata.com/en-us/products/productdetail?partno=GRM188R60J475KE19%23 | C71631 | Exact JLCPCB library import verified; current assembly stock/preorder must be confirmed in quote
C15 | 1 | 22uF | 0603 | Murata | FIT | 22uF ±20%; 6.3V X5R; verify effective capacitance at battery voltage | GRM188R60J226ME15D | https://www.murata.com/en-us/products/productdetail?partno=GRM188R60J226ME15%23 | C440187 | Exact JLCPCB library import verified; current assembly stock/preorder must be confirmed in quote
C17 | 1 | 10nF | 0402 | Murata | FIT | 10nF ±10%; 16V X7R; cap GPIO filter | GRM155R71C103KA01D | https://www.murata.com/en-us/products/productdetail?partno=GRM155R71C103KA01%23 | C85735 | Exact JLCPCB library import verified; current assembly stock/preorder must be confirmed in quote
R1 R2 R3 | 3 | 10k ohm | 0402 | Yageo | FIT | 10k ±1%; 0.063W; I2C and Hall INT pull-ups | RC0402FR-0710KL | https://yageogroup.com/component-documentation/download/specsheet/RC0402FR-0710KL | C60490 | Exact JLCPCB library import verified; current assembly stock/preorder must be confirmed in quote
R4 R5 | 2 | 100k ohm | 0402 | Yageo | FIT | 100k ±1%; 0.063W; nRESET and cap GPIO pull-ups | RC0402FR-07100KL | https://yageogroup.com/component-documentation/download/specsheet/RC0402FR-07100KL | C60491 | Exact JLCPCB library import verified; current assembly stock/preorder must be confirmed in quote
BT1 | 1 | CR2032 holder BS-08-B2AA020-R | SMT holder 24.1x15.7mm / 5.8mm maximum height | MYOUNG / JLCPCB C964787 | FIT | Bottom-mounted holder; raw library pin1 positive / pin2 negative; cell positive face toward hatch; battery inserted after reflow | BS-08-B2AA020-R | https://jlcpcb.com/partdetail/MYOUNG-BS_08_B2AA020R/C964787 | C964787 | Exact JLCPCB library import verified; confirm stock and double-sided assembly process in quote
TP_VDD TP_GND TP_SWDIO TP_SWDCLK TP_RESET | 5 | SWD pogo land | 1.2mm diameter underside pad | PCB copper | BARE PAD | GND land has 0.4mm plated drill; remaining four pads undrilled |  |  |  | Excluded from SMT assembly
BATTERY | 1 | CR2032 primary lithium cell | 20x3.2mm | Battery supplier | MECHANICAL | Positive face toward underside hatch; insert after reflow; replace with PCB and holder fixed |  |  |  | Excluded from SMT assembly
ENCODER_MAGNET | 1 | Diametric neodymium magnet | 6x2mm | Magnet supplier | MECHANICAL | Verify diametric magnetization; calibration with final phone and cell |  |  |  | Excluded from SMT assembly
GPIO_SCL GPIO_SDA GPIO_HALL_INT | 3 | Signal diagnostic land | 0.55mm via land / 0.30mm drill | PCB copper | BARE PAD | Local GPIO escape and fine probe access; no component fitted |  |  |  | Excluded from SMT assembly

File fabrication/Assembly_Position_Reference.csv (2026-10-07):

Designator | Mid_X_mm | Mid_Y_mm | Layer | Authored_Rotation_deg
U1 | -7.5 | 5 | top | 270
C4 | -10 | 0.7 | top | 0
C9 | -7.5 | 0.5 | top | 0
C15 | -6 | -3.5 | top | 180
C5 | -12.4 | 8.42 | top | 180
C7 | 0 | 5.5 | top | 0
C8 | -2.2 | 6 | top | 0
C10 | -7.4 | 12 | top | 90
C16 | -4.8 | 9.9 | top | 90
C18 | -8.2 | 9.4 | top | 0
R4 | -4.2 | 0.7 | top | 180
U2 | 0 | 0 | top | 0
C6 | -1.6 | 1.2 | top | 0
R1 | 2.3 | 1.5 | top | 0
R2 | 2.3 | 0 | top | 0
R3 | 2.3 | -1.5 | top | 0
SW1 | 12.65 | 0 | top | 90
R5 | 8 | 0 | top | 0
C17 | 9.5 | 0 | top | 90
X1 | -0.00012699999999998823 | 7.999999999999999 | top | 90
C1 | 2.3 | 7.3 | top | 0
C2 | 0 | 10.5 | top | 0
X2 | -13 | 5.8 | top | 270
C11 | -14.8 | 6.7 | top | 270
C12 | -14.8 | 4.6 | top | 90
L1 | -2.8 | 4.4 | top | 0
L2 | -0.6000000000000001 | 4.4 | top | 0
C3 | -3.1 | 2.4 | top | 270
ANT1 | 0.02603500000000003 | 16.9 | top | 0
BT1 | -1.200000 | 0.000000 | bottom | 0

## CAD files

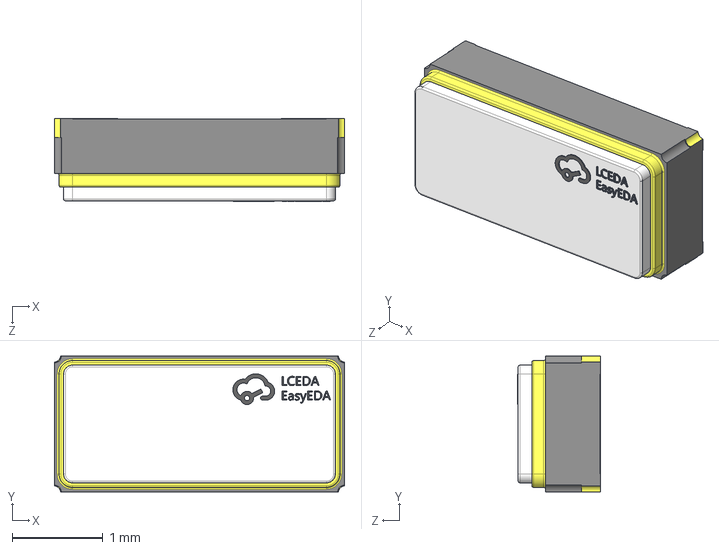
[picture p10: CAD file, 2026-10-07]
imports/ABS07_32_768KHZ_9_T/ABS07_32_768KHZ_9_T.step
3.20 x 1.50 x 0.92 mm

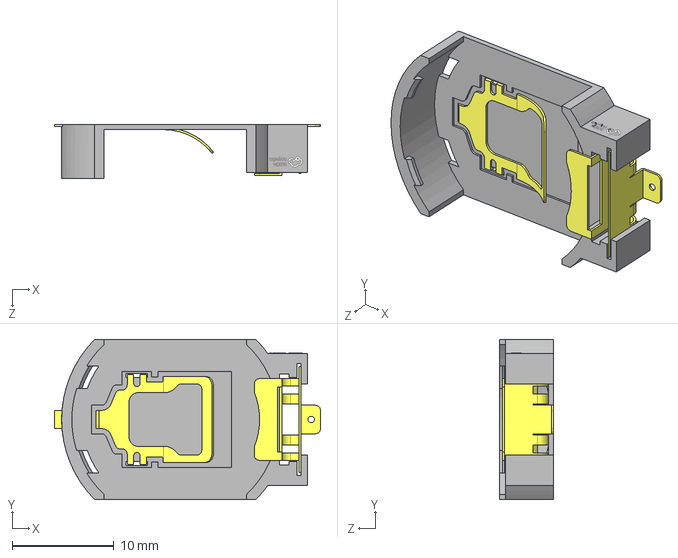
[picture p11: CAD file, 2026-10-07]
imports/BS_08_B2AA020_R/BS_08_B2AA020_R.step
26.1 x 15.7 x 5.31 mm

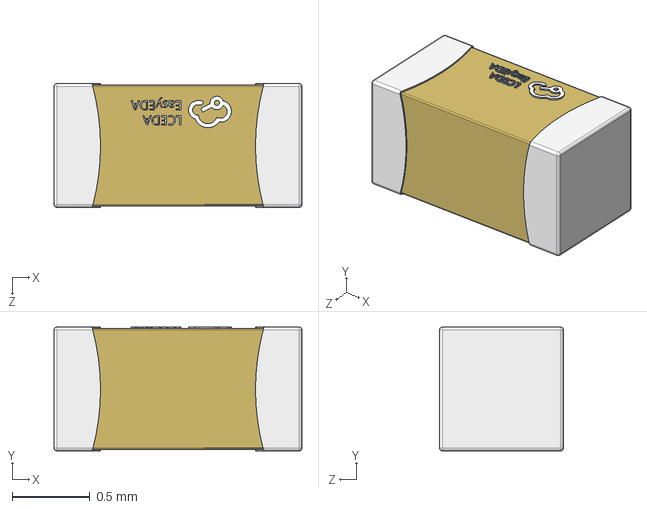
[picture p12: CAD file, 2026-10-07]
imports/CL10B105KA8NNWC/CL10B105KA8NNWC.step
1.60 x 0.8 x 0.8 mm

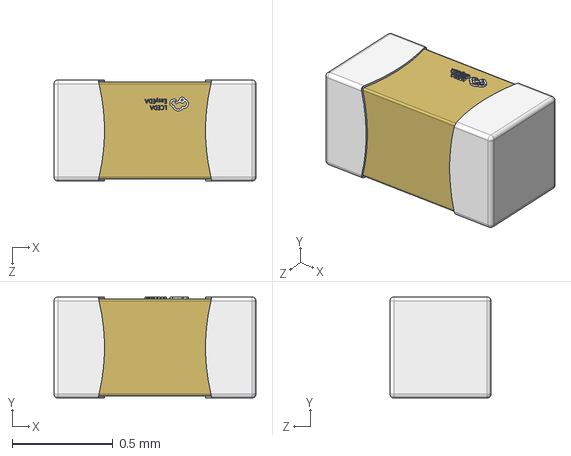
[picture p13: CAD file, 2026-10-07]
imports/GJM1555C1HR80WB01D/GJM1555C1HR80WB01D.step
1.00 x 0.5 x 0.5 mm

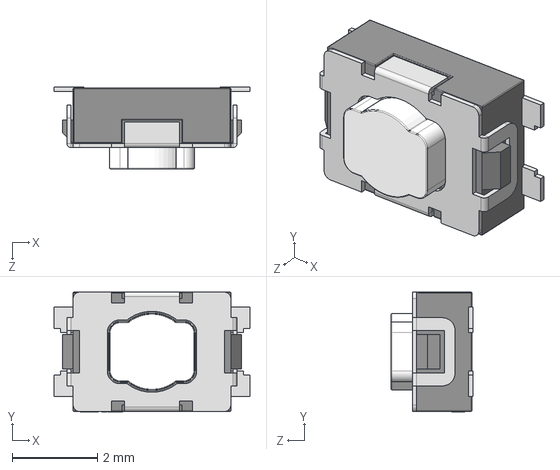
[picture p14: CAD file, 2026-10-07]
imports/KMR232NGULCLFS/KMR232NGULCLFS.step
4.60 x 2.81 x 1.92 mm

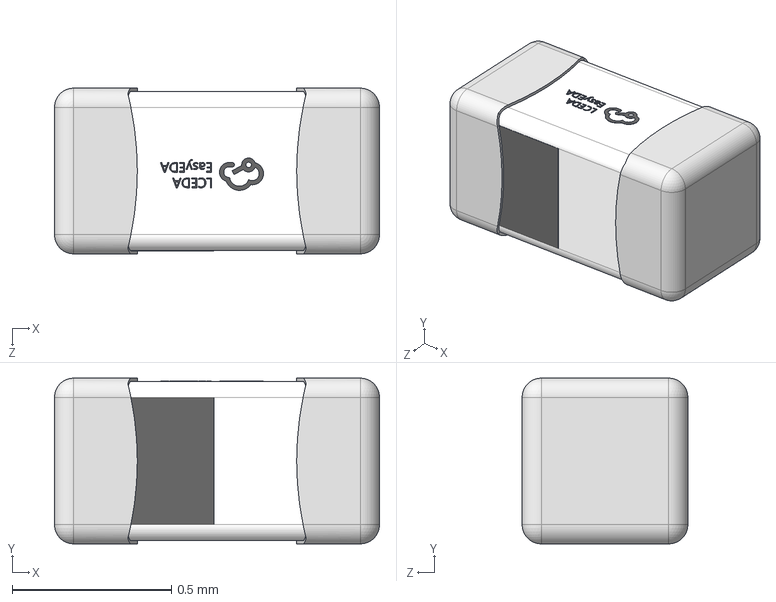
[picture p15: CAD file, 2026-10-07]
imports/LQG15HS6N8G02D/LQG15HS6N8G02D.step
1.02 x 0.52 x 0.52 mm

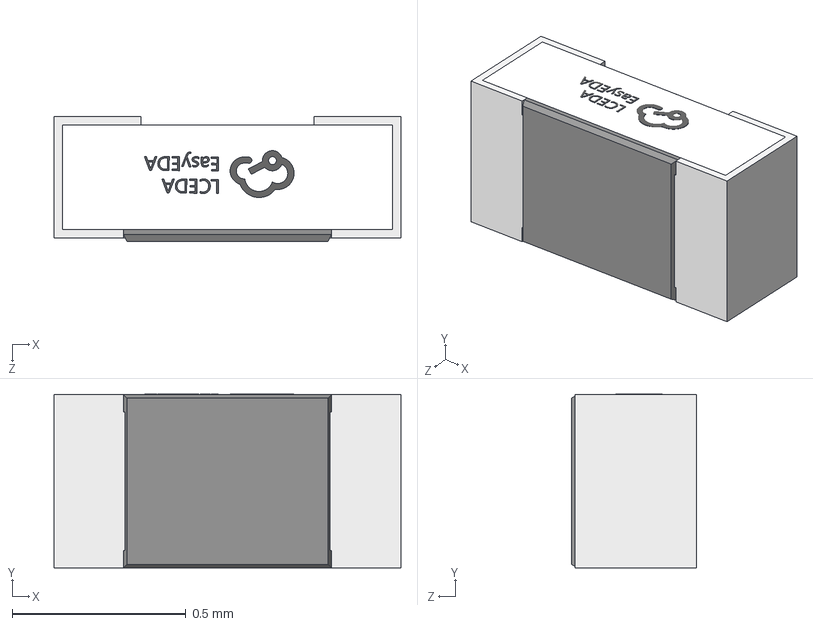
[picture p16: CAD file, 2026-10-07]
imports/RC0402FR_07100KL/RC0402FR_07100KL.step
1.00 x 0.501 x 0.36 mm

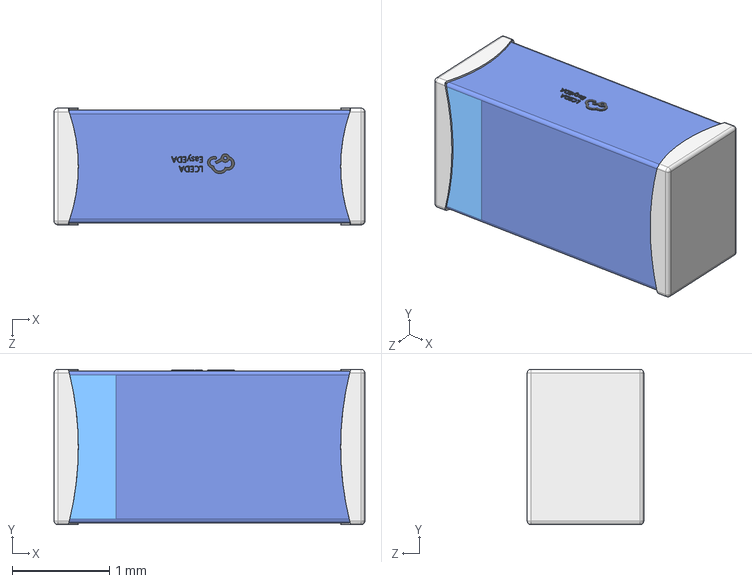
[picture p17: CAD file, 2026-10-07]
imports/RFANT3216120A5T/RFANT3216120A5T.step
3.20 x 1.60 x 1.20 mm

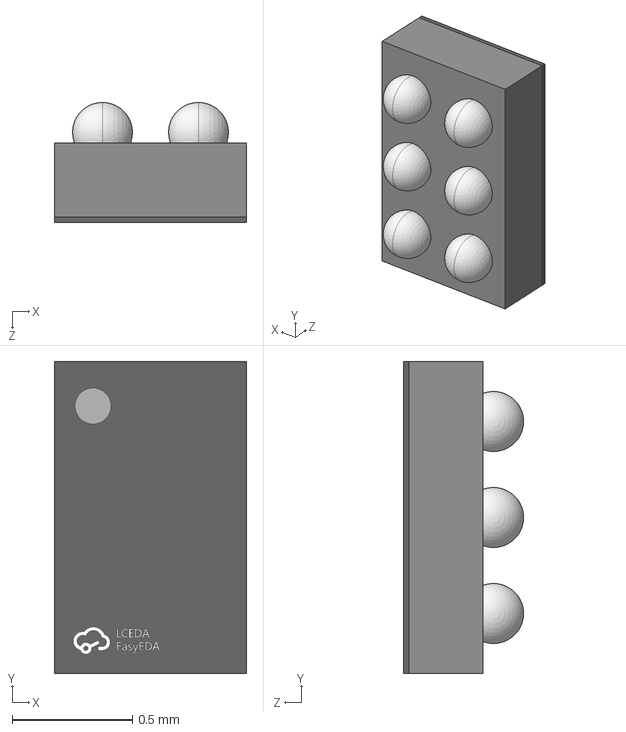
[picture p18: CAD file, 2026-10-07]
imports/TMAG3001A2YBGR/TMAG3001A2YBGR.step
0.8 x 1.30 x 0.501 mm

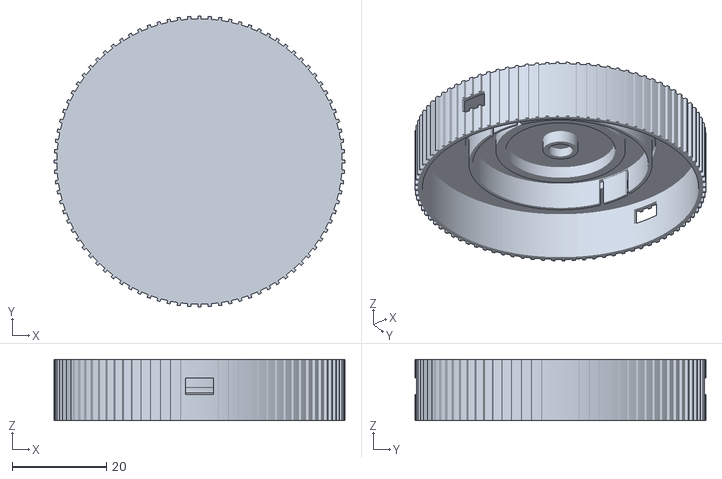
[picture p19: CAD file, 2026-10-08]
mechanical/Circuit_Models/Rotating_Cap.obj
61.6 x 61.6 x 13.0

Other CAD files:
imports/LQG15HS3N9B02D/LQG15HS3N9B02D.step
imports/ABS07_32_768KHZ_9_T/ABS07_32_768KHZ_9_T.obj
imports/BS_08_B2AA020_R/BS_08_B2AA020_R.obj
imports/CL10B105KA8NNWC/CL10B105KA8NNWC.obj
imports/GJM1555C1HR80WB01D/GJM1555C1HR80WB01D.obj
imports/GRM1555C1H101JA01D/GRM1555C1H101JA01D.obj
imports/GRM1555C1H120JA01D/GRM1555C1H120JA01D.obj
imports/GRM155R71C103KA01D/GRM155R71C103KA01D.obj
imports/GRM155R71C104KA88D/GRM155R71C104KA88D.obj
imports/GRM188R60J226ME15D/GRM188R60J226ME15D.obj
imports/GRM188R60J475KE19D/GRM188R60J475KE19D.obj
imports/KMR232NGULCLFS/KMR232NGULCLFS.obj
imports/LQG15HS3N9B02D/LQG15HS3N9B02D.obj
imports/LQG15HS6N8G02D/LQG15HS6N8G02D.obj
imports/NRF52810_QFAA_R/NRF52810_QFAA_R.obj
imports/NRF52810_QFAA_R/NRF52810_QFAA_R.step
imports/RC0402FR_07100KL/RC0402FR_07100KL.obj
imports/RC0402FR_0710KL/RC0402FR_0710KL.obj
imports/RFANT3216120A5T/RFANT3216120A5T.obj
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

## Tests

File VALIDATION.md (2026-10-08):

# PCB Rev A — top-access revision 1.0.6 validation — 8 October 2026

The final source and supplied routed circuit were checked using the pinned local tscircuit 0.0.2748 / CLI 0.1.2253. All previews and fabrication exports use this same routed JSON. The source-build SHA-256 hashes are recorded in `validation/summary.json`; previous publication reports are archived under `validation/history/`.

| Check | Result |
|---|---|
| TypeScript typecheck | Pass |
| Netlist | 0 errors, 0 warnings |
| Pin specification | 0 errors, 0 warnings |
| Source diagnostics | 0 errors, 0 warnings |
| Schematic placement | Pass; no placement violations reported |
| PCB placement | 0 errors, 0 warnings |
| Routing difficulty | Advisory congestion estimate; completed routing validated below |
| Routed build | 0 errors, 0 warnings; 89 routed traces and 47 vias |
| Full tscircuit library validator | 0 errors, 0 warnings |
| Trace-length analysis | All 20 electrical nets analyzed |
| Crystal routing | All eight signal branches at most 10 mm, with zero vias |
| Gerber-derived copper shorts, both layers | 0 shorts |
| Revised 14.0 mm enclosure | All 13 reference solids valid; 4 main printable parts; zero unintended solid collisions |
| Fitted component positions | 30 components: 29 top and 1 bottom; DNP/bare lands excluded |
| Enclosure in circuit 3D | 12 mechanical models aligned within 0.0001 mm of CAD mesh bounds; portable OBJ/MTL URLs |
| Electrical revision comparison | All electrical, PCB and imported component CAD records identical to checked v1.0.3; metadata hash excluded |

All eight CLI check types passed. The complete routed build and the separate full library validator contain zero errors and zero warnings. The full trace-length reports, individual crystal branch lengths and exact source hashes are included in `validation/`. `bun run check:all` repeats the checks and rejects actionable placement issues, asynchronous tool exceptions, error records and warning records.

The CLI's `net.SWDCLK` length report omits its manually linked source branch and reports 0 mm. The supplied routed JSON contains that complete copper connection, with a planar length of 23.13246 mm. `validation/routing-geometry.json` independently totals the routed copper in each of the 20 connectivity groups; the raw CLI output is retained. Connectivity and both-layer shorts checks pass.

The unmodified TSCI JLCPCB imports and all 30 fitted component meshes pass `validation/check-imports.mjs`. SW1 uses shared imported KMR2 geometry while retaining its original 2 N manufacturer part number; the substitute’s catalog identifier is deliberately not assigned.

The source now uses `assembly.device` and 12 named `assembly.cadassembly` elements to include the released enclosure beside the populated PCB. Mechanical electronics/holder dummies are excluded. The three outer shells are translucent in the circuit view; print STL and STEP geometry remains solid. `validation/check-enclosure.mjs` verifies asset hashes, current CAD parameters, model positions and exported GLB bounds, and is included in `bun run check:all`.

`validation/compact-glb-audit.json` verifies the downloadable GLB reduction to fit the registry upload limit. All retained geometry buffers, triangle order, node transforms, electronic normals and PCB textures are unchanged. Identical buffers share storage and sequential enclosure indices are implicit. Optional enclosure normals and unused UV arrays are omitted; GLTF viewers derive the flat face normals. The full CLI build remains available locally in `dist/index/3d.glb`.

The confirmed encoder is a diametrically magnetized neodymium Ø5 × 1.5 mm disc. The revised cap uses a Ø5.2 mm pocket and 0.2 mm roof shim. Its nominal sensor air gaps remain 1.8 mm released and 1.3 mm pressed. CAD regeneration found zero unintended solid intersections. Magnet grade, sensor field margin and rotation accuracy still require a prototype measurement.

The bottom cover has 24 Ø5.25 × 1.55 mm pockets for the ordered Ø5 × 1.5 mm discs, on a Ø49.25 mm pitch circle. The geometry audit checks the actual disc count/volume, open pocket interiors, intact 0.6 mm pocket floors, minimum 1.178 mm pocket webs, 0.8 mm tray/housing rims and clearance in released/pressed states. The continuous backing-ring recess remains accessible with the tray removed. Its shielding performance, the discs' magnetization, attachment force and phone/Hall compatibility have not been measured. The new cap, housing and solid bottom cover form a matched set.

Top service removes the hatch, hatch posts and two M2 screws. Two deliberate release ports operate the cap latches without interrupting the retaining roof. The geometry audit checks key/housing clearance, nominal 0.10 mm released lip clearance, 0.20 mm latch/PCB clearance, the solid center floor and nine upward board/holder/cell extraction positions. No rigid intersections occur along this sampled path. `validation/top-access-key-lift-audit.json` separately checks the keys against rigid cap/grip material at 0, 0.15, 0.3 and 0.5 mm lift; the two intentionally flexing latch zones are explicitly excluded. Withdraw the keys after the initial 0.5 mm lift. Repeated latch cycles, screw retention and populated-board removal still require physical testing.

The MCU and sensor pins explicitly define power, ground, open-drain I2C, pull-up and required connections. Crystals use native electrical models; both signal pairs and their load-cap branches stay on the top layer. Passive manufacturer parts are specified in BOM.csv. Bare copper test points are excluded from physical component assembly. The explicit parts engine preserves authored supplier identifiers and datasheet pin models; no DRC is disabled.

## JLCPCB review — current sensor retained

The rerouted board uses regular-size **0.30 mm drill / 0.55 mm land** vias. Green soldermask accommodates the sensor's **0.20 mm** mask bridges. The sensor remains TMAG3001A2YBGR as requested; target **Standard assembly, both sides, ENIG**. [JLCPCB's current rigid-board requirements](https://jlcpcb.com/capabilities/pcb-capabilities) and [assembly capabilities](https://jlcpcb.com/capabilities/pcb-assembly-capabilities) were reviewed on 7 October 2026.

| Independent measurement | Result |
|---|---|
| Minimum routed trace width | 0.11 mm |
| Minimum copper-to-outline clearance | 0.350 mm |
| Copper, pad, drill and hole clearance checks | 0 violations; details in `validation/jlc-geometry-audit.json` |
| Actual exported mask bridges and legend strokes/clearances | Pass; details in `validation/jlc-gerber-audit.json` |
| Complete SMT mask and paste coverage | Every exposed SMT land has an opening; all fitted lands have paste; bare/DNP pads have none |
| Single-board drill density | 52585 holes/m² |
| Conservative exposed ENIG area upper bound, both sides combined / single board area | 16.97% |

These measurements cover the single board. The carrier panel's tooling holes, breakaway tabs and fiducials require CAM review. The single-board Gerbers need JLCPCB panelization into a carrier at least 70 × 70 mm with 5 mm rails. `README.md` contains order settings and the unresolved sourcing/assembly details. The two `JLCPCB_*_Quote_Draft.csv` files have 30 matching fitted designators (BT1 bottom); rotations need supplier-model review.

BT1 is the exact imported MYOUNG BS-08-B2AA020-R / C964787. Its maximum manufacturer height of 5.8 mm determines the enclosure stack; the imported visual model is shorter. The cell clears the rigid holder body. An unloaded negative spring contact overlaps the nominal cell by 2.62 mm³, recorded separately as a contact-fit estimate; retention and deflection require a physical test. Hatch posts leave 0.260 mm nominal clearance to the nearest SWD pad edge. The supplied enclosure is a prototype fit handoff.

The core omitted paste for the 48 rounded QFN lead pads. `export-gerbers.mjs` adds these at the core’s usual 70% linear reduction and removes bare/DNP paste. Imported copper geometry is unchanged; the exported mask and paste completeness are independently audited. The QFN exposed-pad aperture remains a single 3.22 mm square, pending assembler segmentation review.

Bottom-side holder mounting adds a second assembly side. Confirm reflow order, retention/fixture needs and costs with JLCPCB. Normal Standard PCBA, stencil, feeder, inspection, ENIG and panelization costs remain. See [JLCPCB's surcharge rules](https://jlcpcb.com/help/article/in-what-cases-will-there-be-charged-extra) and [assembly pricing](https://jlcpcb.com/help/article/pcb-assembly-price). No final supplier quote or CAM approval has been obtained. This package is for quotation and engineering review; it is not released for an assembly order.

## Physical and fabrication review still required

- The mounting-hole pattern inherited from the enclosure leaves only 0.25 mm nominal FR4 outside each hole. Obtain fabricator acceptance for this prototype; revise the mounting pattern/enclosure together for a stronger production web.
- The imported WCSP has 0.20 mm lands versus TI’s recommended 0.23 mm; the assembler must accept or resolve that difference. The QFN exposed-pad stencil aperture and authored assembly rotations also need review. The supplied position CSV is a coordinate reference, not a supplier-qualified machine file.
- The new RF feed/ground layout has not been measured for impedance or BLE performance. Tune matching and verify crystal startup in the populated, final phone/MagSafe assembly.
- Verify Hall field range, offsets, rotation accuracy and power consumption with the actual diametric magnet, coin cell and attachment magnets installed.
- Fit-test the commercial holder contacts, battery insertion/removal, cap pusher tolerance and printed flexure return. The compatible cap retains the full circumference grip.
- Firmware and the phone application are not part of this PCB deliverable. Firmware must keep the MCU in LDO mode (DCDCEN = 0), configure the sensor address override for sleep operation, integrate wrapped angles and implement the two-second reset hold.

This is a checked prototype design and editable handoff; the populated hardware has not been tested. No PCB order has been placed.

## Registry publication

The registry entrypoint `published.circuit.json` preserves this exact 0.30 mm drill / 0.55 mm land board. It is byte-identical to the checked `dist/index/circuit.json` output recorded above. The saved-board build is checked again for publication. Current reports are in `validation/`; the previous release’s reports are archived under `validation/history/`.

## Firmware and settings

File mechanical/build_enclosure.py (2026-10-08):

"""MagSafe BLE fidget mechanical prototype, units mm, CadQuery >=2.6.

Run: python mechanical/build_enclosure.py --out work/enclosure
The STEP assembly contains separate named components. Print STL files are
already oriented on Z=0. Reference parts and CAD solids use assembly coordinates.
Attachment geometry fits the specified discs; holding force and magnetic
compatibility require testing with the ordered magnets and intended phone.
"""
from pathlib import Path
import argparse, json, math, itertools
import cadquery as cq

HERE = Path(__file__).resolve().parent
ap = argparse.ArgumentParser()
ap.add_argument('--out', type=Path, default=HERE/'export')
ap.add_argument('--parameters', type=Path, default=HERE/'enclosure-parameters.json')
ap.add_argument('--mesh-out', type=Path, default=None)
args = ap.parse_args()
P = json.loads(args.parameters.read_text())
OUT = args.out.resolve()
for d in ['STEP_Parts', 'Print_STL', 'Reference_STL', 'Views', 'Validation']:
    (OUT/d).mkdir(parents=True, exist_ok=True)

def disk(r, z, h, x=0, y=0):
    return cq.Workplane('XY').workplane(offset=z).center(x,y).circle(r).extrude(h).val()
def annulus(ri, ro, z, h):
    return cq.Workplane('XY').workplane(offset=z).circle(ro).circle(ri).extrude(h).val()
def box(sx,sy,sz,x=0,y=0,z=0):
    return cq.Workplane('XY').box(sx,sy,sz).val().translate((x,y,z+sz/2))
def compound(shapes):
    return cq.Compound.makeCompound(shapes)
def fuse_all(shapes):
    result=shapes[0]
    for sh in shapes[1:]: result=result.fuse(sh)
    return result.clean()
def sector(ri,ro,z,h,start,end):
    sh = cq.Workplane('XZ').polyline([(ri,z),(ro,z),(ro,z+h),(ri,z+h)]).close().revolve(end-start,(0,0),(0,1)).val()
    return sh.rotate((0,0,0),(0,0,1),start)
def radial_box(r,length,width,z,h,angle):
    return box(length,width,h,x=r,z=z).rotate((0,0,0),(0,0,1),angle)
def cone(rb,rt,z,h,x=0,y=0):
    return cq.Solid.makeCone(rb,rt,h,cq.Vector(x,y,z))

Rbody=P['body_diameter']/2
Rcap=P['cap_diameter']/2
Rbase=P['attachment_flange_diameter']/2
grip_bottom=P['cap_grip_bottom_z']
grip_inner=Rcap-0.6-P['cap_grip_wall']
Rskirt=P['skirt_outer_radius']
Rskirt_i=Rskirt-P['skirt_wall']
Rbore=Rskirt+P['radial_running_clearance']
Rlip=Rskirt+P['snap_lip_projection']
Rgroove=Rlip+0.3
pcb_z=P['pcb_bottom_z']; pcb_top=pcb_z+P['pcb_thickness']
deck_z=P['overall_height']-1.2
body_top=deck_z-1.8
hard_stop_z=body_top+P['button_travel']
magnet_z=pcb_top+P['sensor_height']+P['encoder_released_airgap']
pad=P['phone_pad_thickness']; skin=P['bottom_skin_thickness']
skin_top=pad+skin
mag_z=skin_top+P['magnet_adhesive_thickness']
mag_top=mag_z+P['attachment_magnet_thickness']
shield_z=mag_top+P['magnet_adhesive_thickness']
shield_top=shield_z+P['shield_thickness']
flange_top=shield_top+0.8
mag_ri=P['magnet_region_inner_diameter']/2
mag_ro=P['magnet_region_outer_diameter']/2
mc=P['attachment_pocket_clearance']
mount_r=16.2
mount_angles=[45+i*360/P['flexure_count'] for i in range(P['flexure_count'])]
mounts=[(mount_r*math.cos(math.radians(a)),mount_r*math.sin(math.radians(a))) for a in mount_angles]

assert Rskirt_i > P['pcb_diameter']/2 + 0.2, 'PCB fouls rotating skirt'
assert Rbody-Rgroove >= 0.7, 'Groove wall too thin'
assert Rbase > mag_ro+mc+1, 'Attachment flange too small'
assert P['encoder_released_airgap']-P['button_travel'] >= 0.5, 'Pressed sensor gap too small'
assert P['flexure_count'] in (3,4)
assert P['attachment_mode'] in ('envelope','vendor_sectors','disc_array')
assert P['battery_access']=='top'
assert P['snap_tab_count']==len(P['snap_tab_center_degrees'])==2
assert P['cap_service_port_bottom_z']+P['cap_service_port_height']<P['snap_lip_top_z'], 'Release port cuts the retaining roof'
assert Rskirt-P['snap_tab_wall']-P['cap_release_deflection']-P['pcb_diameter']/2>=0.2-1e-6, 'Released latch fouls PCB edge'
assert Rlip-P['cap_release_deflection']<Rbore, 'Released latch cannot pass the bore'
assert grip_inner-Rbase >= P['radial_running_clearance']-1e-6, 'Outer grip fouls lower flange'
assert grip_bottom-P['button_travel'] >= 0.5-1e-6, 'Pressed outer grip too close to phone plane'
assert P['cap_top_groove_depth'] <= 0.4, 'Top grip leaves too little deck thickness'

# Full-footprint cap. The outer grip sleeve wraps down around the stationary
# flange; the separate inner skirt retains and guides the cap. Keep the existing
# shoulder stop so the extended sleeve cannot become the button travel stop.
cap=disk(Rcap-0.6,deck_z,1.2)
shroud=annulus(Rbody-0.85,Rcap-0.6,hard_stop_z,deck_z-hard_stop_z+0.02)
grip_sleeve=annulus(grip_inner,Rcap-0.6,grip_bottom,deck_z-grip_bottom+0.02)
cap=cap.fuse(shroud,grip_sleeve)
profile=[(Rskirt_i,P['skirt_bottom_z']), (Rskirt,P['skirt_bottom_z']),
         (Rskirt,P['snap_lip_top_z']-0.65),(Rlip,P['snap_lip_top_z']-0.4),
         (Rlip,P['snap_lip_top_z']),(Rskirt,P['snap_lip_top_z']),
         (Rskirt,deck_z+0.02),(Rskirt_i,deck_z+0.02)]
skirt=annulus(Rskirt_i,Rskirt,P['skirt_bottom_z'],deck_z+0.02-P['skirt_bottom_z'])
for angle in P['snap_tab_center_degrees']:
    half=P['snap_tab_arc_degrees']/2
    latch=cq.Workplane('XZ').polyline(profile).close().revolve(2*half,(0,0),(0,1)).val().rotate((0,0,0),(0,0,1),angle-half)
    skirt=skirt.fuse(latch)
    # Thin only the two flexing tongues. The remaining skirt still guides the cap.
    skirt=skirt.cut(sector(Rskirt_i-0.05,Rskirt-P['snap_tab_wall'],P['skirt_bottom_z']-0.05,
                         P['snap_slot_root_z']-P['skirt_bottom_z']+0.05,angle-half-2,angle+half+2))
    for boundary in [angle-half-1.5,angle+half+1.5]:
        skirt=skirt.cut(radial_box(Rskirt,3.0,P['snap_slot_width'],P['skirt_bottom_z']-0.05,
                                 P['snap_slot_root_z']-P['skirt_bottom_z']+0.05,boundary))
cap=cap.fuse(skirt)
ribs=[radial_box(Rcap-0.55,1.10,0.70,grip_bottom,P['overall_height']-grip_bottom,
                i*360/P['cap_edge_rib_count']) for i in range(P['cap_edge_rib_count'])]
cap=cap.fuse(*ribs).intersect(disk(Rcap,grip_bottom,P['overall_height']-grip_bottom)).clean()
# Recessed radial grooves give traction during thumb rotation without increasing
# height. The central magnet roof is untouched; grooves can bridge when printed
# with the top face on the bed.
groove_inner=P['cap_top_groove_inner_radius']; groove_outer=Rcap-1.7
grooves=[radial_box((groove_inner+groove_outer)/2,groove_outer-groove_inner,
          P['cap_top_groove_width'],P['overall_height']-P['cap_top_groove_depth'],
          P['cap_top_groove_depth']+0.1,i*360/P['cap_top_groove_count'])
          for i in range(P['cap_top_groove_count'])]
cap=cap.cut(compound(grooves)).clean()
# Continuous annular force transfer reaches the one stationary off-axis switch
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

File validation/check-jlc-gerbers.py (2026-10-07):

"""Audit actual mask and legend primitives in this project's Gerber export."""
import hashlib, json, re, sys, zipfile
from pathlib import Path
from shapely.geometry import Point, LineString, box
from shapely.ops import unary_union
from shapely.affinity import rotate, translate

archive=Path(sys.argv[1])
circuit_path=Path(sys.argv[2] if len(sys.argv)>2 else 'dist/index/circuit.json')
c=json.loads(circuit_path.read_text())
def read_primitives(data):
    apertures={}; shapes=[]; widths=[]; dcode=None; previous=None
    for line in data.splitlines():
        m=re.fullmatch(r'%ADD(\d+)([CR]),([\d.]+)(?:X([\d.]+))?\*%',line)
        if m:
            apertures[int(m[1])]=(m[2],float(m[3]),float(m[4] or m[3]));continue
        m=re.fullmatch(r'%ADD(\d+)(HORZPILL|VERTPILL),([\d.]+)X([\d.]+)X[\d.]+X[\d.]+\*%',line)
        if m:
            apertures[int(m[1])]=(m[2],float(m[3]),float(m[4]));continue
        if line.startswith('%') or line.startswith('G04'):continue
        m=re.fullmatch(r'D(\d+)\*',line)
        if m:dcode=int(m[1]);continue
        assert not line.startswith(('G02','G03','G36','G37')), 'Unsupported mask/legend primitive: '+line
        m=re.fullmatch(r'X([+-]?\d+)Y([+-]?\d+)D0([123])\*',line)
        if not m:continue
        x,y=float(m[1])/1e6,float(m[2])/1e6;op=int(m[3])
        if op in (1,3):
            kind,w,h=apertures[dcode]
            if op==3:
                if kind=='C':g=Point(x,y).buffer(w/2,quad_segs=64)
                elif kind=='R':g=box(x-w/2,y-h/2,x+w/2,y+h/2)
                else:
                    r=min(w,h)/2
                    ends=[(x-w/2+r,y),(x+w/2-r,y)] if w>=h else [(x,y-h/2+r),(x,y+h/2-r)]
                    g=LineString(ends).buffer(r,quad_segs=64)
            else:
                assert kind=='C' and previous is not None
                g=LineString([previous,(x,y)]).buffer(w/2,quad_segs=32)
                widths.append(w)
            shapes.append(g)
        previous=(x,y)
    return shapes,widths

with zipfile.ZipFile(archive) as z:
    mask={layer:read_primitives(z.read(name).decode())[0] for layer,name in [('top','F_Mask.gbr'),('bottom','B_Mask.gbr')]}
    silk={layer:read_primitives(z.read(name).decode()) for layer,name in [('top','F_SilkScreen.gbr'),('bottom','B_SilkScreen.gbr')]}
    paste={layer:read_primitives(z.read(name).decode())[0] for layer,name in [('top','F_Paste.gbr'),('bottom','B_Paste.gbr')]}
def pad_geometry(p):
    if p['shape']=='circle':return Point(p['x'],p['y']).buffer(p['radius'],quad_segs=64)
    if p['shape']=='rect':return box(p['x']-p['width']/2,p['y']-p['height']/2,p['x']+p['width']/2,p['y']+p['height']/2)
    assert p['shape'] in ('pill','rotated_pill'),p['shape']
    w,h=p['width'],p['height'];r=min(w,h)/2
    ends=[(-w/2+r,0),(w/2-r,0)] if w>=h else [(0,-h/2+r),(0,h/2-r)]
    return translate(rotate(LineString(ends).buffer(r,quad_segs=64),p.get('ccw_rotation',0),origin=(0,0)),p['x'],p['y'])
components={e['pcb_component_id']:e for e in c if e['type']=='pcb_component'}
mask_union={layer:unary_union(shapes).buffer(.000002) for layer,shapes in mask.items()}
paste_union={layer:unary_union(shapes) for layer,shapes in paste.items()}
pad_coverage=[];paste_coverage=[];excluded_paste=[]
for p in [e for e in c if e['type']=='pcb_smtpad']:
    if not p.get('is_covered_with_solder_mask'):
        missing_area=pad_geometry(p).difference(mask_union[p['layer']]).area
        if missing_area>1e-7:pad_coverage.append({'pad':p['pcb_smtpad_id'],'missingMaskAreaMm2':missing_area})
    center=Point(p['x'],p['y'])
    fitted=not components[p['pcb_component_id']].get('do_not_place')
    present=paste_union[p['layer']].covers(center)
    if fitted and not present:paste_coverage.append(p['pcb_smtpad_id'])
    if not fitted and present:excluded_paste.append(p['pcb_smtpad_id'])
board=next(e for e in c if e['type']=='pcb_board')
u2=next(e for e in c if e['type']=='pcb_component' and e['center']=={'x':0,'y':0})
sensor=[]
for g in mask['top']:
    if abs(g.centroid.x)<=.201 and abs(g.centroid.y)<=.401:sensor.append(g)
assert len(sensor)==6,len(sensor)
bridge=min(a.distance(b) for i,a in enumerate(sensor) for b in sensor[i+1:])
legend={}
for layer,(shapes,widths) in silk.items():
    openings=unary_union(mask[layer])
    violations=[{'bounds':list(g.bounds),'maskClearanceMm':round(g.distance(openings),6)} for g in shapes if g.distance(openings)<.15-1e-5]
    legend[layer]={'minimumDrawStrokeMm':min(widths),'minimumMaskClearanceMm':min(g.distance(openings) for g in shapes),'violations':violations}

# Conservative upper bound: every opening is counted as exposed copper,
# including mounting holes and other non-copper areas.
exposed_bound=sum(unary_union(openings).area for openings in mask.values())
from shapely.geometry import Polygon
area=Polygon([(p['x'],p['y']) for p in board['outline']]).area
drill_count=sum(e['type'] in ('pcb_via','pcb_plated_hole','pcb_hole') for e in c)
result={'circuitJsonSha256':hashlib.sha256(circuit_path.read_bytes()).hexdigest(),
    'gerberZipSha256':hashlib.sha256(archive.read_bytes()).hexdigest(),
    'sensorMaskBridgeMm':round(bridge,6),'minimumGreenMaskBridgeMm':.1,
    'silkscreen':legend,'boardAreaMm2':area,'drillCount':drill_count,
    'drillDensityPerSquareMetre':drill_count/area*1e6,
    'exposedEnigAreaUpperBoundPercentOfSingleBoardArea':exposed_bound/area*100,
    'maskCoverageViolations':pad_coverage,'fittedPadsMissingPaste':paste_coverage,'bareOrDnpPadsWithPaste':excluded_paste,
    'panelToolingAndTabsExcludedFromDensity':True}
Path('work/jlc-gerber-audit.json').write_text(json.dumps(result,indent=2)+'\n')
print(json.dumps(result,indent=2))
assert bridge>=.1-1e-5
assert not pad_coverage and not paste_coverage and not excluded_paste, 'Incomplete mask/paste export'
assert all(v['minimumDrawStrokeMm']>=.15-1e-5 and not v['violations'] for v in legend.values()), 'Legend requires repair'
assert result['drillDensityPerSquareMetre']<150000
assert result['exposedEnigAreaUpperBoundPercentOfSingleBoardArea']<30

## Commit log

2026-10-07 Publish validated Rev A fidget counter prototype with preserved routing
    [Assembly_Position_Reference.csv, BOM.csv, Rotating_Cap_for_PCB_RevA.step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]
2026-10-07 Update fidget counter to 0.30 mm drill revision
    [BOM.csv, JLCPCB_BOM_Quote_Draft.csv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]
2026-10-07 Import JLCPCB library footprints and component models
    [ABS07_32_768KHZ_9_T.obj, ABS07_32_768KHZ_9_T.step, Assembly_Position_Reference.csv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]
2026-10-07 Add imported CR2032 holder and revise battery hatch enclosure
    [Assembly_Position_Reference.csv, BOM.csv, BS_08_B2AA020_R.obj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]
2026-10-07 Integrate enclosure assembly and size encoder magnet to 5 x 1.5 mm
    [Battery_Fasteners.obj, Battery_Hatch.obj, Bottom_Cover.obj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]
2026-10-07 Compact downloadable assembly GLB for registry upload limit
2026-10-08 Add bottom tray for 24 ordered-size disc magnets
    [Bottom_Cover.obj, Bottom_Cover.step, Bottom_Cover.stl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]
2026-10-08 Keep the attachment layout preview as a compact PNG
2026-10-08 Reduce assembly preview storage without changing triangles
2026-10-08 Move battery service to a releasable cap and solid bottom
    [Battery_Fasteners.obj, Battery_Hatch.obj, Battery_Hatch.step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]
2026-10-21 Document SWD programming and board bring-up
2026-10-23 Publish inward PCB snap mounts and standard TC2030 interface
2026-10-23 Pack checked CAD exports for smaller cloud startup input
2026-10-28 Replace programming test pads with five-pin JST-SH connector
2026-10-30 Generate the hosted website after restoring checked circuit artifacts
